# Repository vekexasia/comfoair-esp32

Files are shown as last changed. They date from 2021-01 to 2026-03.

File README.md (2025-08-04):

Need help? Join the [Discord](https://discord.gg/dUSSRezJXC) or open an issue.

# Comfoair Q 350 ESPHome bridge

This software let you use a ESP32 + CAN Transceiver to interact with the Comfoair Q 350 unit.

It does expose all known informations of your Comfoair unit via ESPHOME and let you control the air flow via Home Assistant as well.

It does allow you to integrate the unit on Home Assistant as depicted below:
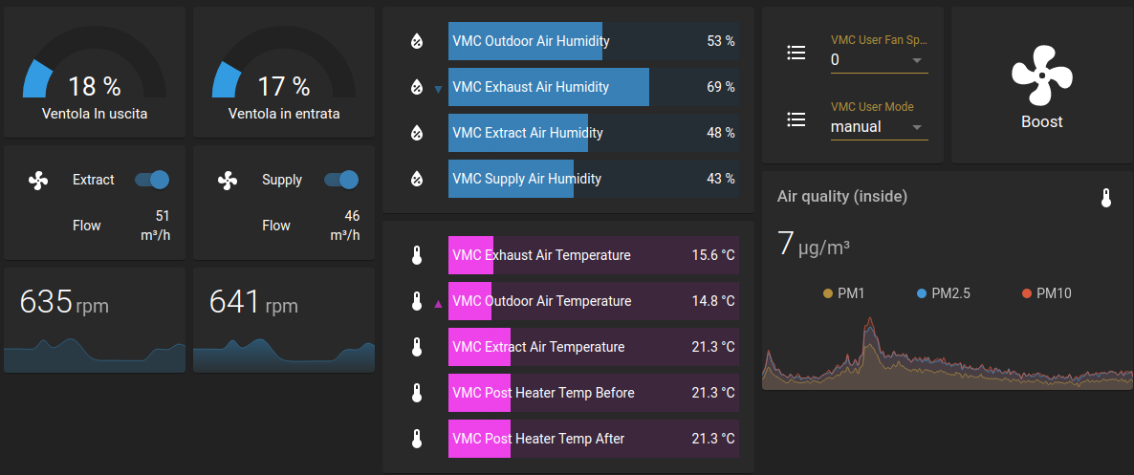
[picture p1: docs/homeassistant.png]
Comfoair Q 350 Home Assistant


## Custom PCB

Inside the [docs/pcb folder](docs/pcb) you can find both gerber file and BOM. Files are provided as is. It's up to you to check data and schematic correctness.

This repository is meant to be working with the custom pcb above. But you can always buy components separately such as [Waveshare SN65HVD230](https://www.banggood.com/Waveshare-SN65HVD230-CAN-Bus-Module-Communication-CAN-Bus-Transceiver-Development-Board-p-1693712.html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) and a voltage regulator as well as an ESP32 of your choice and it will work.

The pcb will look like this once soldered and mounted.

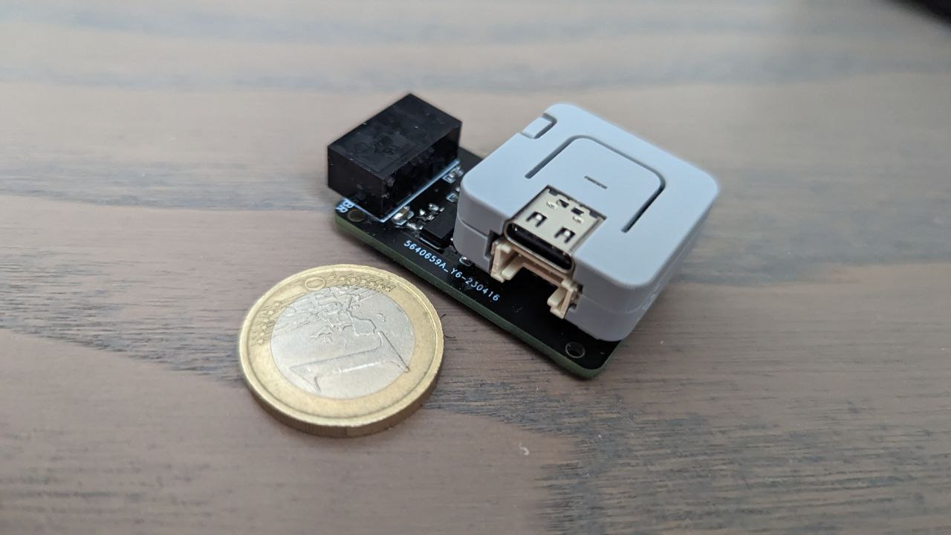
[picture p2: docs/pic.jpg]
PCB Comfoair Q 350 3D Print


## DIY

Prerequisites for custom build:

* `ESP32` -> [link](https://amzn.to/3pe0XVP)
* `DC-DC converter` -> [link](https://amzn.to/39ar22v)
* `RJ45 Female` -> [link](https://amzn.to/3sNx3tH)
* `Can Transceiver` -> [Waveshare SN65HVD230](https://www.banggood.com/Waveshare-SN65HVD230-CAN-Bus-Module-Communication-CAN-Bus-Transceiver-Development-Board-p-1693712.html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)
+ Some ethernet cable

Here a simple schematic. made by @mat3u

```
---------------+        +---------------+                 +-------------+
(oran/red)12V  o--------o IN+      OUT+ o-----------------o VIN         |
               |        |   [LM2596S]   |                 |             |
(brown)   GND  o--------o IN-      OUT- o-----------------o GND         |
               |        +---------------+                 |             |
    [RJ45]     |                                          |   [ESP32]   |
  [ComfoAir]   |                                          |             |
               |        +-------------------------+       |             |
(w/blue) CAN_L o--------o CAN_L               3v3 o-------o 3v3         |
(blue)   CAN_H o--------o CAN_H               GND o-------o GND         |
---------------+        |                         |       |             |
                        |   [SN65HVD230]   CAN TX o-------o 25          |
                        |                  CAN RX o-------o 21          |
                        +-------------------------+       +-------------+
``````

## esphome conf

To include this repo use the external_components configuration like so:

```yaml
# ...
external_components:
  - source: github://vekexasia/comfoair-esp32
    components: [ comfoair ]
api:
  custom_services: true # <--- This is needed

comfoair:

# ...
```

# Home Assistant Services

The component exposes 4 services.

- comfoair_send_command
- comfoair_send_hex
- comfoair_update_all
- comfoair_req_update_service

**NOTE**: the prefix could differ depending on your esphome device name.

**comfoair_send_command**: allows one "command" parameter. The value of the param can be one of the following pre-bundled commands:

- ventilation_level_0
- ventilation_level_1
- ventilation_level_2
- ventilation_level_3
- boost_10_min
- boost_20_min
- boost_30_min
- boost_60_min
- boost_end
- auto
- manual
- bypass_activate_1h
- bypass_deactivate_1h
- bypass_auto
- ventilation_supply_only
- ventilation_supply_only_reset
- ventilation_extract_only
- ventilation_extract_only_reset
- temp_profile_normal
- temp_profile_cool
- temp_profile_warm

In case you need more flexibility you can use the `comfoair_send_hex` service like follows:
```
service: esphome.comfoair_send_hex
data:
  hexSequence: "8415070100000000100e000000"
```
^^ the above is equivalent to ventilation_extract_only (which has an inner timer of 1h)

**comfoair_update_all**: this service will request an update of all the values from the Comfoair unit. This is useful in case you want to force an update of all the values.

**comfoair_req_update_service**: this service will request an update of a specific value from the Comfoair unit. This is useful in case you want to force an update of a specific value. You're required to pass the `PDOID` of the service to update

## Climate Entity

The component will expose a climate entity with heat,cool,auto modes and all the fan speeds.

Furthermore current indoor humidity and temperature as well as current target temperature will be shon as in the picture below.

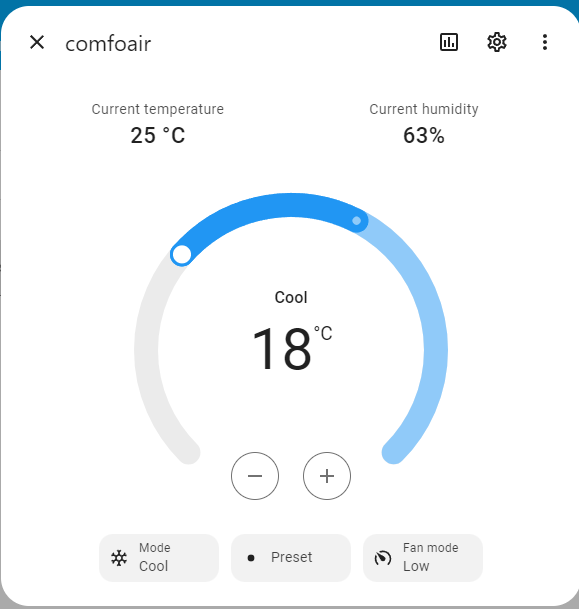
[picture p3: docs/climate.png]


The climate entity can also be used to set the fan speed, and the mode (heat, cool, auto).

## Global filters

Since this component posts data as soon as it receives it, sometimes it might be useful to avoid spamming home assistant with updates.

To avoid this, you can set the `global_filters`. This accepts the same filters as the `filters` parameter in the `sensor` component.

For example, let's say you want to throttle the sensors for 10s.

```yaml

comfoair:
  global_filters:
    - throttle: 10s
```

Obviously, you can always set the filter on a per-sensor basis.

```yaml
comfoair:
  supply_fan_speed:
    name: supply_fan_speed
    disabled_by_default: false
    force_update: false
    unit_of_measurement: rpm
    accuracy_decimals: 0
    filters:
      - or:
          - throttle: 300s
          - delta: 100.0
```

**NOTE**: when setting `global_filters` that **does** takes precedence over the `filters` set on a per-sensor basis.
## Credits

A lot of this repo was inspired by the reverse engineering [here](https://github.com/marco-hoyer/zcan/issues/1).
If you'd like to know more how the unit communicates, head over

* [here](https://github.com/michaelarnauts/aiocomfoconnect/blob/master/docs/PROTOCOL-RMI.md)
* [and here](https://github.com/michaelarnauts/aiocomfoconnect/blob/master/docs/PROTOCOL-PDO.md)

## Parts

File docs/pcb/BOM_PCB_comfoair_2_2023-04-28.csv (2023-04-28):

ID | Name | Designator | Footprint | Quantity | Manufacturer Part | Manufacturer | Supplier | Supplier Part | Price | Pins
1 | 100nF | C1 | C0603 | 1 | CL10B104KO8NNNC | SAMSUNG(三星) | LCSC | C66501 |  | 2
2 | CON4 ATOR PCB MOLEX | CN2 | 39512-1004 | 1 | 39532-1004 | Molex | Mouser | 538-39532-1004 |  | 4
3 | 10kΩ | R1 | R0603 | 1 | 0603WAF1002T5E | UNI-ROYAL(厚声) | LCSC | C25804 |  | 2
4 | 120Ω | R2 | R0603 | 1 | 0603WAF1200T5E | UNI-ROYAL(厚声) | LCSC | C22787 |  | 2
5 | SN65HVD230DR | U1 | SOIC-8_L4.9-W3.9-P1.27-LS6.0-BL | 1 | SN65HVD230DR | TI(德州仪器) | LCSC | C12084 | 0.173 | 8
6 | AMS1117-3.3_C347222 | U3 | SOT-223-4_L6.5-W3.5-P2.30-LS7.0-BR | 1 | AMS1117-3.3 | UMW(广东友台半导体) | LCSC | C347222 | 0.006 | 4
7 | PZ254V-11-04P_C2691448 | H3 | HDR-TH_4P-P2.54-V-M | 1 | PZ254V-11-04P | XFCN(兴飞) | LCSC | C2691448 | 0.004 | 4
8 | PZ254V-11-05P | H4 | HDR-TH_5P-P2.54-V-M | 1 | PZ254V-11-05P | XFCN(兴飞) | LCSC | C492404 | 0.005 | 5
9 | 10uF | C3,C5 | C0603 | 2 | CL10A106MA8NRNC | SAMSUNG(三星) | LCSC | C96446 | 0.004 | 2

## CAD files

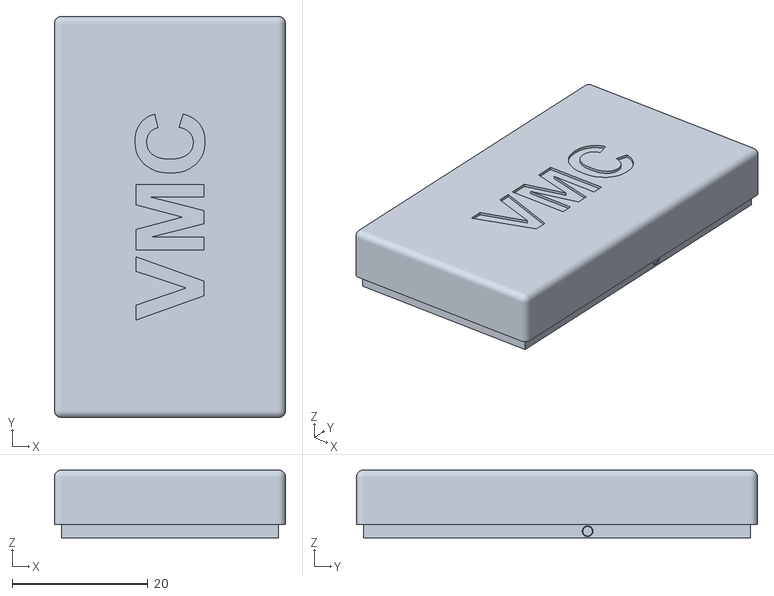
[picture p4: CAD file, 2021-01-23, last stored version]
docs/3d/cappella-box-vmc.stl
34.0 x 59.0 x 10.0

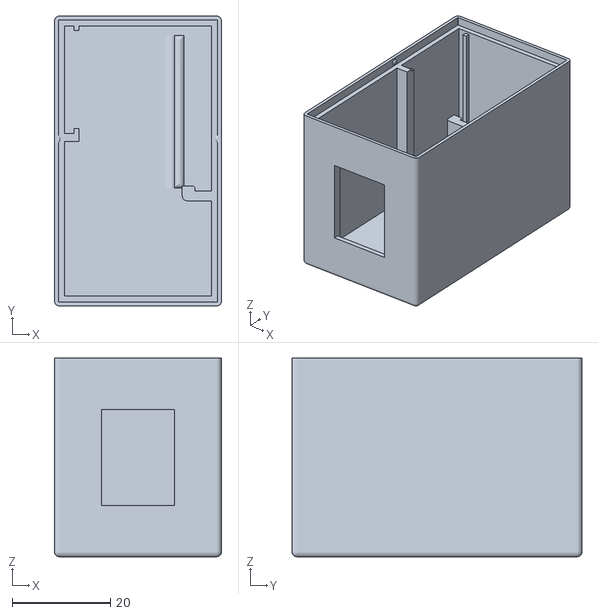
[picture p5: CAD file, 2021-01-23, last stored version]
docs/3d/box-vmc-sotto-finale.stl
34.0 x 59.0 x 40.4

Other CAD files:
docs/3d/box-vmc v20.f3d
docs/box-vmc v20.f3d

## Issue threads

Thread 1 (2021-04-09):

Connection schema for the ESP32 and CAN

asmanea, 2021-04-09:
I hope I'm not asking too much! Could you please upload a connection scheme or image of the end result (not inside the box) between VMC and ESP32/CAN? The steps provided are enough for a skilled person, but for a newbie might be cumbersome to setup. Thanks!

Uriziel01, 2021-06-26:
Just run power (+12V and GND) into the step down converter (set it to output 3.3V first!) and then connect the Step down ouput 3.3V+GND into both ESP32 and the CAN Transceiver. Next connect RX/TX from CAN Transceiver into pins 4 and 5 of ESP32.
Maybe we could create a graphical form of wiring if this will help you ;)

asmanea, 2021-06-26:
Thanks! Will order the parts, and try to do the connection schema. Will update shortly.

Uriziel01, 2021-06-26:
Sure, it is pretty straightforward. I've actually done the build today, should take you around 30minutes.
My only issue was waaaay to small of a box to fit everything inside of it 😄 Now onto HomeAssistant configuration.

vekexasia, 2021-06-26:
Glad to see you did this project. The box is just enough to fit all components but you need to be good at tetris :D

Uriziel01, 2021-06-28:
BTW @vekexasia would you be willing to merge in some MQTT tweaks like implementation of HA MQTT Discovery or migrating commands into using payload instead of just topics. Currently it does not work well with HA without manual synchronization automation scripts.
Not sure if I should just implement this locally or do a PR into your repository? 😉

Uriziel01, 2021-06-28:
@asmanea I've uploaded simple connection diagram so it is easy even for a beginner. Keep in mind (as you can see in the photo) I DID NOT USED this exact diagram because I hate destroying ethernet cables without a reason so I've just plugged in cable into the RJ45 socket and the last 4 pins correspond to the pins on the left (+12V, GND, CAN_H, CAN_L), this way you use just a ethernet cable with RJ45 on both ends.

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

vekexasia, 2021-06-28:
@Uriziel01 ofcourse. Also  if you'd like to add the diagram! that'd be perfect. even if i used the mini format factor.

svde, 2021-06-30:
> RJ45 socket and the last 4 pins correspond to the pins on the left (+12V, GND, CAN_H, CAN_L),

How does this correspond with TIA-568B color coding?

| ComfoAir | RJ45 pin | TIA 568B |
| --- | --- | --- |
| CAN_L | 1 | white-orange |
| CAN_H | 2 | orange |
| GND | 3 | white-green |
| 12V | 4 | blue |

Niki206cc, 2021-07-05:
Good morning, i'm new with HA and ESPN32. I bought all but i want to be sure i will connect correctly because i have a different device. Can you pls confirm me the connections are ok? Thanks
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

svde, 2021-07-05:
> Can you pls confirm me the connections are ok? Thanks

Yes, that's correct.

pistacjusz, 2021-07-06:
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

Are you sure of the attached wiring diagram?
I connected the circuit as shown in the attached below photos, but it doesn't work completely. I can read the values of temperature, humidity, etc. but I cannot change the state of the recuperator (e.g. change the fan speed). I think the HA is sending the mqtt command correctly. Do you have any idea why this doesn't work?
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

svde, 2021-07-06:
> but I cannot change the state of the recuperator (e.g. change the fan speed).
Same here.

I've been trying to investigate (capturing CAN traffic with a raspberry pi + CANhat), haven't figured out what pattern to watch for in the candump output to see if the mqtt command (mosquitto_pub -h 127.0.0.1 -t comfoair/commands/boost_10_min -m 1) is making it onto the canbus.

Uriziel01, 2021-07-18:
@pistacjusz @svde Yes I'm 100% sure because it is working at my place for the last few weeks and except for a WiFi stability issues (not sure what is the problem here, just have to restart the ESP now and then) it is working just fine. Are you sure you are sending correct MQTT msg with corrent topic? Matching your defined `MQTT_PREFIX` from fw files?

pistacjusz, 2021-07-18:
@Uriziel01 On your schematic you connect Can_H recuperator to Can_L transceiver and Can_L recuperator to Can_H transceiver.
When I connect my circuit like this, nothing happens.

Below log from `mosquitto_sub -v -t 'comfoair / commands / #'`

comfoair / commands / ventilation_level 0
comfoair / commands / ventilation_level 1
comfoair / commands / ventilation_level 3
comfoair / commands / set_mode auto
comfoair / commands / set_mode manual
comfoair / commands / ventilation_level 0
comfoair / commands / boost_10_min (null)
comfoair / commands / ventilation_level_3 (null)

and second `mosquitto_sub -v -t 'comfoair / #'`

comfoair / exhaust_fan_speed 805
comfoair / supply_fan_speed 899
comfoair / away_indicator false
comfoair / exhaust_fan_flow 58
comfoair / supply_fan_flow 56
comfoair / ah_actual 0.65
comfoair / exhaust_fan_speed 810
comfoair / supply_fan_speed 901
comfoair / exhaust_fan_flow 59
comfoair / exhaust_fan_speed 813
comfoair / supply_fan_speed 902
comfoair / exhaust_fan_speed 816
comfoair / supply_fan_speed 903
comfoair / exhaust_fan_speed 818

Here line from secrets.h file
#define MQTT_PREFIX "comfoair"

svde, 2021-07-18:
Sending the commands:

$ mosquitto_pub -t comfoair/commands/boost_10_min -m 1
$ mosquitto_pub -t comfoair/commands/boost_10_min -m 2
$ mosquitto_pub -t comfoair/commands/boost_10_min -m 2
$ mosquitto_pub -t comfoair/commands/boost_10_min -m 2

and they show up like this:

$ mosquitto_sub -v -t 'comfoair/commands/#'
comfoair/commands/boost_10_min 1
comfoair/commands/boost_10_min 2
comfoair/commands/boost_10_min 2
comfoair/commands/boost_10_min 2

I'm also running candump, shouldn't I be seeing something like this being sent over the canbus?

#define CMD_boost_10_min                    { 0x84, 0x15, 0x01, 0x06, 0x00, 0x00, 0x00, 0x00, 0x58, 0x02, 0x00, 0x00, 0x03, 0x00, 0x00, 0x00 }

Uriziel01, 2021-07-19:
@pistacjusz Haha, just noticed this :D Of course the correct method is the other way around 😄

Both of your commands seems ok, did you tried to connect to serial of ESP32 and check if it correctly receives the MQTT message and tries to send the CAN command?

pistacjusz, 2021-07-20:
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

There is some data from the serial monitor after sending the MQTT message

```
supply_fan_speed - 1161-------new message from broker-----
channel:comfoair/commands/boost_60_min
data:
Received: boost_60_min
1F034051 00 84 15 01 06 00 00 00
1F034051 01 00 10 0E 00 00 03 00
1F034051 82 00 00
1F054051 00 84 15 01 06 00 00 00
1F054051 01 00 10 0E 00 00 03 00
1F054051 82 00 00
1E4041 X 22 4
Decoded :)
exhaust_fan_speed - 1026354041 X 255 0
Decoded :)

exhaust_fan_speed - 1024354041 X 256 0
Decoded :)
ah_actual - 0.8610000001 X 0
1000001A X 0
10000001 X 0
1000001A X 0
-------new message from broker-----
channel:comfoair/commands/ventilation_level_3
data:
Received: ventilation_level_3
1F074051 00 84 15 01 01 00 00 00
1F074051 81 00 01 00 00 00 03
1F014051 00 84 15 01 01 00 00 00
1F014051 81 00 01 00 00 00 03
1000001A X 0
1E4041 X 28 4
Decoded :)

supply_fan_speed - 1138-------new message from broker-----
channel:comfoair/commands/ventilation_level
data:1
Received: comfoair/commands/ventilation_level
ventilation_level_1
1F034051 00 84 15 01 01 00 00 00
1F034051 81 00 01 00 00 00 01
1F054051 00 84 15 01 01 00 00 00
1F054051 81 00 01 00 00 00 01
688041 X 10
1E4041 X 20 4
Decoded :)
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
Uriziel01, 2022-01-04:
I do not have any option/KNX/LAN box installed, just a can transceiver and it is definitely not getting hot.

piwko28, 2022-01-04:
Thanks for your answer, it's important hint.
I meant voltage between CAN_L and GND and CAN_H and GND. Red connector has 12V as well.
I'll try with another can transceiver then, maybe the one is broken.

piwko28, 2022-01-08:
I had wrong wiring and tried to use espcam. It works perfectly with esp32.

pistacjusz, 2022-02-22:
After many tries, I finally got the project started. The cause of the problems was the factory broken can transciver. I changed it to another one and everything started working immediately, I can read the recuperator states and control it. Greetings:)

quentindavid, 2022-08-26:
Hi, thanks a lot for this project and this topic which are really helpful !
Something I don't quite understand : why would you use the ethernet cable if you can just plug CAN_H, CAN_L, +24V and GND with regular cables in the connector on the left of the RJ45 ?
Is it fine if I connect my CAN transceiver using this port instead of RJ45 ?

Uriziel01, 2022-08-26:
Sure you can use the terminals, the RJ45 is just more convenient, especially when setting things up I had few times some issue and the only way to resolve it was to just physically unplug the RJ45 cable as it was preventing the whole unit from booting up properly.

pyzimmer, 2022-10-18:
I think you can wire the +12v directly to the VIN pin of the ESP32, because ESP board have a regulator. You don't need DC-DC converter.

Uriziel01, 2022-10-18:
@pyzimmer I do not recommend to hook up 12V directly to ESP32 board, it does in fact have a regulator but it is a linear regulator not a switching one, if regulating down from 12V to 5V it will cause regulator to dissipate lots of heat.

At around 160mA-250mA average power draw for ESP32 and 7V potential difference (12-5) it's around 1.12W to 1.75W of power that will get converter into heat. It's fine for a short period but in this case device will run 24/7.

Hans-0, 2023-01-10:
For this project I am using the D1 Mini ESP32 ESP-32 Wifi + Bluetooth (CP2102) - see image:

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

Vekexasia says in his description:
can_rx -> pin 5 of esp32
can_tx -> pin 4 of esp32

Which pins are those exactly on my esp32?

Uriziel01, 2023-01-10:
**D4** is the **GPIO4** (**IO4** in your case)
**D5** is the **GPIO5** (**IO5** in your case)

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

rpiLovers, 2023-06-21:
Hi, thanks a lot for this project and this topic!
I just need some help with installation (ESPHOME newbie....)
I have WT32-ETH01 ESP32  board, Waveshare SN65HVD230 CAN Tranceiver Module and Buck Converter LM2596 3A.
In home assistant I see the ESP board and all of the parameters (i used the external_components:   - source: github://vekexasia/comfoair-esp32).
The problem is that I am not sure which ports to use and to change in the code.
I think RXD (GPIO05) and TXD (GPIO17).
How can I change the code in ESPHOME? Your board uses PIn 4 and 5.
Hope someone can helpout.
I would love to get my Q450 working on the network.
Thanks in advance.
HDR

pat1300, 2023-06-21:
> @asmanea I've uploaded simple connection diagram so it is easy even for a beginner. Keep in mind (as you can see in the photo) I DID NOT USED this exact diagram because I hate destroying ethernet cables without a reason so I've just plugged in cable into the RJ45 socket and the last 4 pins correspond to the pins on the left (+12V, GND, CAN_H, CAN_L), this way you use just a ethernet cable with RJ45 on both ends.
>
> 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

@Uriziel01 : Hi, are you sure of your connection diagram? CAN_L (white wire) is connected to CANH of the transceiver , and CAN_H ( yellow) is conncetd to CANL . I think it should be the reverse.  Your photos are correct, but not the diagram I think.
Best regards,
Patrick

Uriziel01, 2023-06-22:
@pat1300 Just checked and I'm sure of the fact that it is definetly wrong 😄 **Of course CAN_L should be connected to CANL and CAN_H to CANH.**

@rpiLovers I guess you can just change 25/21 pins combo in the `comfoair-esp32/components/comfoair
/__init__.py` file. @vekexasia mentioned that he will be possibly adding custom pins configuration in the near future here https://github.com/vekexasia/comfoair-esp32/issues/46#issuecomment-1533125530

poingZ, 2023-06-27:
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

@pat1300 are you powering the ESP32 with the 3.3V DC-DC convertor? My setup doesn't work and can't find out why, I'm powering the ESP32 (mini) via USB and the ESP32 is giving 3.3v to the CAN module (I measured it). I don't see why this shouldn't work ...

vekexasia, 2024-03-11:
Hello @Uriziel01 @pat1300 @rpiLovers You can now do it via rx_pin and tx_pin configuration flags

Closed 2024-03-11.

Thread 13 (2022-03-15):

Help to install on ESP32

bekaxe, 2022-03-15:
Can anyone provide a short description on how to install this on an ESP32?
Or refer to a proper documentation?

I managed to install the included libraries wifi, comfoair, mqtt and ota by adding them to the libraries folder of the IDE.
But it is missing the esp32_can.h
Where do I find the correct library for the CAN controller?

tobiaranz, 2022-03-16:
Hi, I managed to install on ESP32 using VS code with platformio extension. I only had to add secrets.h in src folder (defining WIFI_SSID, WIFI_PASS, MQTT_USER, MQTT_PASS, MQTT_PREFIX "comfoair", MQTT_HOST and MQTT_PORT).
After that I had to add the lib "knolleary/PubSubClient@^2.8" under lib_deps in platformio.ini file.

I'm not sure if this is the best way to set everything up, but it worked for me, hope this helps you.

bekaxe, 2022-03-18:
@tobiaranz: thanks for the hint, I have done this and it helped me to get further.
I have now a dependency which I do not get resolved.
`.pio/libdeps/esp12e/FreeRTOS-Kernel/include/FreeRTOS.h:59:10: fatal error: FreeRTOSConfig.h: No such file or directory`

Which is the right lib to include?

makselod, 2022-04-16:
Hi all,
its my first time with visual studio.

Can some one tell me what I must do to upload?

`Verbose mode can be enabled via `-v, --verbose` option
CONFIGURATION: https://docs.platformio.org/page/boards/espressif32/mhetesp32minikit.html
PLATFORM: Espressif 32 (3.5.0) > MH ET LIVE ESP32MiniKit
HARDWARE: ESP32 240MHz, 320KB RAM, 4MB Flash
DEBUG: Current (esp-prog) External (esp-prog, iot-bus-jtag, jlink, minimodule, olimex-arm-usb-ocd, olimex-arm-usb-ocd-h, olimex-arm-usb-tiny-h, olimex-jtag-tiny, tumpa)
PACKAGES:
 - framework-arduinoespressif32 3.10006.210326 (1.0.6)
 - tool-esptoolpy 1.30100.210531 (3.1.0)
 - tool-mkspiffs 2.230.0 (2.30)
 - toolchain-xtensa32 2.50200.97 (5.2.0)
LDF: Library Dependency Finder -> https://bit.ly/configure-pio-ldf
LDF Modes: Finder ~ chain, Compatibility ~ soft
Found 31 compatible libraries
Scanning dependencies...
Dependency Graph
|-- <SPI> 1.0
|-- <can_common> 0.3.0+sha.07605a2
|-- <ESP32_CAN> 0.2.5+sha.7c3174f
|   |-- <can_common> 0.3.0+sha.07605a2
|   |-- <SPI> 1.0
|-- <PubSubClient> 2.8.0
|-- <WiFi> 1.0
|-- <ESPmDNS> 1.0
|   |-- <WiFi> 1.0
|-- <Update> 1.0
|-- <WebServer> 1.0
|   |-- <WiFi> 1.0
|   |-- <FS> 1.0
Building in release mode
Compiling .pio\build\esp32minikit\src\comfoair\CanAddress.cpp.o
In file included from src\comfoair\CanAddress.cpp:2:0:
src\comfoair\CanAddress.h:5:15: fatal error: map: No such file or directory
compilation terminated.
Compiling .pio\build\esp32minikit\src\comfoair\PubSubClient.cpp.o
Compiling .pio\build\esp32minikit\src\comfoair\comfoair.cpp.o
Compiling .pio\build\esp32minikit\src\comfoair\message.cpp.o
*** [.pio\build\esp32minikit\src\comfoair\CanAddress.cpp.o] Error 1
In file included from src\comfoair\PubSubClient.h:10:0,
                 from src\comfoair\PubSubClient.cpp:8:
C:\Users\daro1\.platformio\packages\framework-arduinoespressif32\cores\esp32/Arduino.h:142:21: fatal error: algorithm: No such file or directory
compilation terminated.
In file included from .pio\libdeps\esp32minikit\PubSubClient\src/PubSubClient.h:10:0,
                 from src\comfoair\message.h:5,
                 from src\comfoair\message.cpp:1:
C:\Users\daro1\.platformio\packages\framework-arduinoespressif32\cores\esp32/Arduino.h:142:21: fatal error: algorithm: No such file or directory
compilation terminated.
In file included from .pio\libdeps\esp32minikit\PubSubClient\src/PubSubClient.h:10:0,
                 from src\comfoair\message.h:5,
                 from src\comfoair\comfoair.h:3,
                 from src\comfoair\comfoair.cpp:1:
C:\Users\daro1\.platformio\packages\framework-arduinoespressif32\cores\esp32/Arduino.h:142:21: fatal error: algorithm: No such file or directory
compilation terminated.
*** [.pio\build\esp32minikit\src\comfoair\PubSubClient.cpp.o] Error 1
*** [.pio\build\esp32minikit\src\comfoair\comfoair.cpp.o] Error 1
*** [.pio\build\esp32minikit\src\comfoair\message.cpp.o] Error 1
============================================================ [FAILED] Took 7.20 seconds ============================================================
Environment    Status    Duration
-------------  --------  ------------
esp32minikit   FAILED    00:00:07.199`

pyto00, 2022-05-10:
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

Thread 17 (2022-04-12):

Esp getting into hanging state after 1-3 days neither sending or receiving data.

Erestes, 2022-04-12:
First of all thanks for the great work on this, works flawlessly with a small but.
My ESP hangs every 1,2,3 days and I need o shut down the unit and enable it back again to restore readings and control. I got the power supplied from the recu, my friend has a separate power via phone charger and it works for him without any issues. Any ideas what may be causing the issues in my case?

vekexasia, 2022-04-12:
Hey, you're not the first one to tell me such issue. Unfortunately my esp32 is running stable since months now. Not a single time I had to powercycle it.

What board are you using? How distant is the WiFi AP from the ESP32?

Erestes, 2022-04-12:
I'm using ESP-WROOM-32
Distance between AP - ESP ca 7-8m through two walls, signal readings on the router = Medium but okay
I have another ESP for voltage/current readings which is bit furhter away and works without issues. I would remove the wifi signal from the equation.
What I haven't done and what I will check next time when it happens is whether the ESP is responding to pings while in hang state.
I wonder if a periodic restart on ESP (for example at midnight) would help, but still wouldn't know what piece of code should be added and where.

Erestes, 2022-04-15:
Interestingly since I posted this issue the ESP didn't crash so far :)

Closed 2022-09-12.

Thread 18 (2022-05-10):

Option Box Connection Error

atomic339, 2022-05-10:
Hi, everything is working good. But I get error "option box connection error". I have to reconnect everything and error disappears but after few hours I get it again.
All commands from mqtt work good, even error appears.

vekexasia, 2022-09-12:
I think the id of the device might conflict to the option box? Did you get this sorted?

atomic339, 2022-09-12:
In my case it was a 2 problems:
- DC-DC converter (I changed to micro usb power supply and works good)
- after wifi lost esp32 can't connect again (someone post here "wifi loop command" - I compiled with this loop and works good)

After this works stable and great

Closed 2022-09-12.

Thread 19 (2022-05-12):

assert failed: xTaskRemoveFromEventList tasks.c

pyto00, 2022-05-12:
I am struggeling with this assert fail error. I found that this is a part of FreeRTOS which I have no knowledge about.
It reboots a few times and then gets stuck.

From the monitor terminal

```
Connecting to INET
.......
WiFi Connected. IP:
192.168.0.45
ESP_SMT init
ESPVMC init
Attempting MQTT connection...connected
Subscribing to: comfoair/commands/auto
Subscribing to: comfoair/commands/boost_10_min

assert failed: xTaskRemoveFromEventList tasks.c:3657 (pxUnblockedTCB)

Backtrace:0x40083835:0x3ffb23400x4008b7e9:0x3ffb2360 0x40090ca9:0x3ffb2380 0x4008d586:0x3ffb24b0 0x4008c8b8:0x3ffb24d0 0x40100c32:0x3ffb2510 0x40100f61:0x3ffb2530 0x400efb26:0x3ffb2550 0x400f14b8:0x3ffb2580 0x400ead15:0x3ffb2620 0x400d8522:0x3ffb2690 0x400d7ab0:0x3ffb26f0 0x400d7e1d:0x3ffb2710 0x400d7e35:0x3ffb2730 0x400d4adb:0x3ffb2750 0x400d4ba3:0x3ffb2790 0x400d4c1e:0x3ffb27e0 0x400d49bc:0x3ffb2800 0x400e0b51:0x3ffb2820
```

Does someone has any pointers for me ?

svde, 2022-05-12:
Same as in my (updated) [comment](https://github.com/vekexasia/comfoair-esp32/issues/13#issuecomment-1123989770) on a previous issue.

pyto00, 2022-05-13:
The code written by @vekexasia is not compatible anymore with the latest ESPRESSIF32 platform.
I went to this overview of all the versions to see what version they where at now.

[https://registry.platformio.org/platforms/platformio/espressif32/versions?version=3.3.0](url)

I then randomly chose a version from 10 months ago.
and edited the platformio.ini config like below.

```
[env:nodemcu-32s]`
platform = platformio/espressif32@3.3.0
board = esp32dev
framework = arduino
monitor_speed = 115200
upload_port = COM20
monitor_port = COM20
lib_deps =
    SPI
	can_common=https://github.com/collin80/can_common.git
	esp32_can=https://github.com/collin80/esp32_can.git
	https://github.com/knolleary/pubsubclient.git
```

the ESP32 does not crash anymore and I was able to send a command.
```
Connecting to INET
.........
WiFi Connected. IP:
192.168.0.45
ESP_SMT init
ESPVMC init
Attempting MQTT connection...connected
Subscribing to: comfoair/commands/auto
Subscribing to: comfoair/commands/boost_10_min
Subscribing to: comfoair/commands/boost_20_min
Subscribing to: comfoair/commands/boost_30_min
Subscribing to: comfoair/commands/boost_60_min
Subscribing to: comfoair/commands/boost_end
Subscribing to: comfoair/commands/bypass_activate_1h
Subscribing to: comfoair/commands/bypass_auto
Subscribing to: comfoair/commands/bypass_deactivate_1h
Subscribing to: comfoair/commands/manual
Subscribing to: comfoair/commands/set_mode
Subscribing to: comfoair/commands/temp_profile_cool
Subscribing to: comfoair/commands/temp_profile_normal
Subscribing to: comfoair/commands/temp_profile_warm
Subscribing to: comfoair/commands/ventilation_extract_only
Subscribing to: comfoair/commands/ventilation_extract_only_reset
Subscribing to: comfoair/commands/ventilation_level
Subscribing to: comfoair/commands/ventilation_level_0
Subscribing to: comfoair/commands/ventilation_level_1
Subscribing to: comfoair/commands/ventilation_level_2
Subscribing to: comfoair/commands/ventilation_level_3
Subscribing to: comfoair/commands/ventilation_supply_only
Subscribing to: comfoair/commands/ventilation_supply_only_reset
-------new message from broker-----
channel:comfoair/commands/ventilation_level_3
data:
Received: ventilation_level_3
1F034051 00 84 15 01 01 00 00 00
1F034051 81 00 01 00 00 00 03
1F054051 00 84 15 01 01 00 00 00
1F054051 81 00 01 00 00 00 03
```

vekexasia, 2022-05-13:
hey @pyto00 can you please open a merge request?

piotrsn, 2022-06-17:
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

This helped me a lot - thank you. The script is now fully working.

vekexasia, 2022-06-17:
Heyhey @piotrsn can you create a MR?

piotrsn, 2022-06-17:
Hey, to be honest I am soo new to this that I don't know how to do it. If
you can give me a guide or a link how to do so, then I will do. Thank you

pt., 17 cze 2022 o 10:55 Andrea ***@***.***> napisał(a):

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

atomic339, 2022-06-27:
If I want to use nodemcu 32S bord do I need to add:
[env:nodemcu-32s] in platformio.ini?

pyto00, 2022-07-03:
> hey @pyto00 can you please open a merge request?

Hi,

The merge request is still pending. Can you initiate the merge ?

vekexasia, 2022-07-03:
sorry pyto didn't see the MR for some reason. I just merged.

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

--

Andrea Baccega
[image: ***@***.***
[image: ***@***.***
[image: Personal site] <http://www.andreabaccega.com/> [image: Linkedin
Profile] <http://it.linkedin.com/in/andreabaccega> [image: Facebook]
<https://www.facebook.com/andrea.baccega> [image: Google+]
<https://plus.google.com/109217393200753135791> [image: Twitter]
<http://twitter.com/veke87> [image: StackOverflow]
<http://stackoverflow.com/users/314407/andrea-baccega> [image: GitHub]
<https://github.com/vekexasia>

Closed 2022-09-12.

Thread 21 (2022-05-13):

commands not accepted by comfoair unit

pyto00, 2022-05-13:
When the ESP32 is connected to the canbus I get an error on de display of the unit itself
`Comfonet error Please check cables`

I can only reset this error when I disconnect the ESP32.
While connected I am able to read out the sensor data but the unit doesn't react on commands.

Comfoair Firmware 1.9.0

Can this be a canbus ID error ? Maybe due to the recent firmare on the comfoair unit ?
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

panosnl, 2022-07-22:
I can send commands without errors to the Q600 with firmware 1.9.1

I only get this error when the eps restarts.

masafra86, 2022-10-01:
I have the same problem, I can't send commands. I receive all the correct data (even if 15/20 minutes after resetting the ESP, connection fails), but I am not able to send commands. Firmware version R1.9.0

masafra86, 2022-11-01:
Today I got again to work on my ESP32 to try to understand the problem, and monitoring the ESP while I was trying to send any command, I found that it never receives any command message. I got back to build the firmware and I found in the logs this:

mpiling .pio/build/az-delivery-devkit-v4/src/main.cpp.o
Compiling .pio/build/az-delivery-devkit-v4/src/mqtt/mqtt.cpp.o
src/comfoair/comfoair.cpp: In member function 'void comfoair::ComfoAir::setup()':
src/comfoair/comfoair.cpp:24:4: warning: ISO C++ forbids converting a string constant to 'char*' [-Wwrite-strings]
   });
    ^
src/comfoair/comfoair.cpp:42:5: note: in expansion of macro 'subscribe'
     subscribe("ventilation_level_0");
     ^
src/comfoair/comfoair.cpp:24:4: warning: ISO C++ forbids converting a string constant to 'char*' [-Wwrite-strings]
   });
    ^
src/comfoair/comfoair.cpp:43:5: note: in expansion of macro 'subscribe'
     subscribe("ventilation_level_1");
     ^
src/comfoair/comfoair.cpp:24:4: warning: ISO C++ forbids converting a string constant to 'char*' [-Wwrite-strings]
   });
    ^
src/comfoair/comfoair.cpp:44:5: note: in expansion of macro 'subscribe'
     subscribe("ventilation_level_2");
     ^
src/comfoair/comfoair.cpp:24:4: warning: ISO C++ forbids converting a string constant to 'char*' [-Wwrite-strings]
   });
    ^
src/comfoair/comfoair.cpp:45:5: note: in expansion of macro 'subscribe'
     subscribe("ventilation_level_3");
     ^
src/comfoair/comfoair.cpp:24:4: warning: ISO C++ forbids converting a string constant to 'char*' [-Wwrite-strings]
   });
    ^
src/comfoair/comfoair.cpp:46:5: note: in expansion of macro 'subscribe'
     subscribe("boost_10_min");
     ^
src/comfoair/comfoair.cpp:24:4: warning: ISO C++ forbids converting a string constant to 'char*' [-Wwrite-strings]
   });
    ^
src/comfoair/comfoair.cpp:47:5: note: in expansion of macro 'subscribe'
     subscribe("boost_20_min");
     ^
src/comfoair/comfoair.cpp:24:4: warning: ISO C++ forbids converting a string constant to 'char*' [-Wwrite-strings]
   });
    ^
src/comfoair/comfoair.cpp:48:5: note: in expansion of macro 'subscribe'
     subscribe("boost_30_min");
     ^
src/comfoair/comfoair.cpp:24:4: warning: ISO C++ forbids converting a string constant to 'char*' [-Wwrite-strings]
   });
    ^
src/comfoair/comfoair.cpp:49:5: note: in expansion of macro 'subscribe'
     subscribe("boost_60_min");
     ^
src/comfoair/comfoair.cpp:24:4: warning: ISO C++ forbids converting a string constant to 'char*' [-Wwrite-strings]
   });
    ^
src/comfoair/comfoair.cpp:50:5: note: in expansion of macro 'subscribe'
     subscribe("boost_end");
     ^
src/comfoair/comfoair.cpp:24:4: warning: ISO C++ forbids converting a string constant to 'char*' [-Wwrite-strings]
   });
    ^
src/comfoair/comfoair.cpp:51:5: note: in expansion of macro 'subscribe'
     subscribe("auto");
     ^
src/comfoair/comfoair.cpp:24:4: warning: ISO C++ forbids converting a string constant to 'char*' [-Wwrite-strings]
   });
    ^
src/comfoair/comfoair.cpp:52:5: note: in expansion of macro 'subscribe'
     subscribe("manual");
     ^
src/comfoair/comfoair.cpp:24:4: warning: ISO C++ forbids converting a string constant to 'char*' [-Wwrite-strings]
   });
    ^
src/comfoair/comfoair.cpp:53:5: note: in expansion of macro 'subscribe'
     subscribe("bypass_activate_1h");
     ^
src/comfoair/comfoair.cpp:24:4: warning: ISO C++ forbids converting a string constant to 'char*' [-Wwrite-strings]
   });
    ^
src/comfoair/comfoair.cpp:54:5: note: in expansion of macro 'subscribe'
     subscribe("bypass_deactivate_1h");
     ^
src/comfoair/comfoair.cpp:24:4: warning: ISO C++ forbids converting a string constant to 'char*' [-Wwrite-strings]
   });
    ^
src/comfoair/comfoair.cpp:55:5: note: in expansion of macro 'subscribe'
     subscribe("bypass_auto");
     ^
src/comfoair/comfoair.cpp:24:4: warning: ISO C++ forbids converting a string constant to 'char*' [-Wwrite-strings]
   });
    ^
src/comfoair/comfoair.cpp:56:5: note: in expansion of macro 'subscribe'
     subscribe("ventilation_supply_only");
     ^
src/comfoair/comfoair.cpp:24:4: warning: ISO C++ forbids converting a string constant to 'char*' [-Wwrite-strings]
   });
    ^
src/comfoair/comfoair.cpp:57:5: note: in expansion of macro 'subscribe'
     subscribe("ventilation_supply_only_reset");
     ^
src/comfoair/comfoair.cpp:24:4: warning: ISO C++ forbids converting a string constant to 'char*' [-Wwrite-strings]
   });
    ^
src/comfoair/comfoair.cpp:58:5: note: in expansion of macro 'subscribe'
     subscribe("ventilation_extract_only");
     ^
src/comfoair/comfoair.cpp:24:4: warning: ISO C++ forbids converting a string constant to 'char*' [-Wwrite-strings]
   });
    ^
src/comfoair/comfoair.cpp:59:5: note: in expansion of macro 'subscribe'
     subscribe("ventilation_extract_only_reset");
     ^
src/comfoair/comfoair.cpp:24:4: warning: ISO C++ forbids converting a string constant to 'char*' [-Wwrite-strings]
   });
    ^
src/comfoair/comfoair.cpp:60:5: note: in expansion of macro 'subscribe'
     subscribe("temp_profile_normal");
     ^
src/comfoair/comfoair.cpp:24:4: warning: ISO C++ forbids converting a string constant to 'char*' [-Wwrite-strings]
   });
    ^
src/comfoair/comfoair.cpp:61:5: note: in expansion of macro 'subscribe'
     subscribe("temp_profile_cool");
     ^
src/comfoair/comfoair.cpp:24:4: warning: ISO C++ forbids converting a string constant to 'char*' [-Wwrite-strings]
   });
    ^
src/comfoair/comfoair.cpp:62:5: note: in expansion of macro 'subscribe'
     subscribe("temp_profile_warm");
     ^
src/comfoair/comfoair.cpp:70:6: warning: ISO C++ forbids converting a string constant to 'char*' [-Wwrite-strings]
     });
      ^
src/comfoair/comfoair.cpp:80:6: warning: ISO C++ forbids converting a string constant to 'char*' [-Wwrite-strings]
     });
      ^

I'm not able to understand what is he saying, but maybe someone has the solution

Closed 2024-03-11.

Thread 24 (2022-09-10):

New configuration for mqtt 2022.12.0

atomic339, 2022-09-10:
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

Do you make a new configuration or the old one will work?

vekexasia, 2022-09-10:
I did change mine. I might commit a new version

atomic339, 2022-09-11:
If you can it will be great

atomic339, 2022-09-15:
Can you help me with this changes?
Put this to my config but sensors don't work:
mqtt:
  sensor:
    # Consumption
    - name: "VMC Power Current"
      state_topic: "comfoair/power_consumption_current"
      unit_of_measurement: W
    - name: "VMC Total Energy Saving"
      state_topic: "comfoair/ah_ytd"
      unit_of_measurement: Wh

# FAns
    - name: "VMC Exhaust Fan Speed"
      state_topic: "comfoair/exhaust_fan_speed"
      unit_of_measurement: rpm
    - name: "VMC Supply Fan Speed"
      state_topic: "comfoair/supply_fan_speed"
      unit_of_measurement: rpm
    - name: "VMC Exhaust Fan Duty"
      state_topic: "comfoair/exhaust_fan_duty"
      unit_of_measurement: rpm
    - name: "VMC Supply Fan Duty"
      state_topic: "comfoair/supply_fan_duty"
      unit_of_measurement: rpm
    - name: "VMC Supply Fan User Speed"
      state_topic: "comfoair/fan_speed"

  # FLOW
    - name: "VMC Exhaust   Fan Flow"
      state_topic: "comfoair/exhaust_fan_flow"
      unit_of_measurement: "m³/h"
    - name: "VMC Supply Fan Flow"
      state_topic: "comfoair/supply_fan_flow"
      unit_of_measurement: "m³/h"

# TEMPS
    - name: "VMC Outdoor Air Temperature"
      state_topic: "comfoair/outdoor_air_temp"
      unit_of_measurement: "°C"
    - name: "VMC Exhaust Air Temperature"
      state_topic: "comfoair/exhaust_air_temp"
      unit_of_measurement: "°C"
    - name: "VMC Extract Air Temperature"
      state_topic: "comfoair/extract_air_temp"
      unit_of_measurement: "°C"
    - name: "VMC Post Heater Temp Before"
      state_topic: "comfoair/post_heater_temp_before"
      unit_of_measurement: "°C"
    - name: "VMC Post Heater Temp After"
      state_topic: "comfoair/post_heater_temp_after"
      unit_of_measurement: "°C"

# Humidity
    - name: "VMC Outdoor Air Humidity"
      state_topic: "comfoair/outdoor_air_humidity"
      unit_of_measurement: "%"
    - name: "VMC Exhaust Air Humidity"
      state_topic: "comfoair/exhaust_air_humidity"
      unit_of_measurement: "%"
    - name: "VMC Extract Air Humidity"
      state_topic: "comfoair/extract_air_humidity"
      unit_of_measurement: "%"
    - name: "VMC Supply Air Humidity"
      state_topic: "comfoair/supply_air_humidity"
      unit_of_measurement: "%"

atomic339, 2022-09-15:
Ok, it was a problem with my board. Works good

Closed 2022-09-15.

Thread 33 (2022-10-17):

Integration with existing UI for CA350

mat3u, 2022-10-17:
Hello,

I was tinkering over weekend to make working this firmware with existing Lovelace controls (eg. https://github.com/mweimerskirch/lovelace-hacomfoairmqtt). Result:

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
I can see temperatures, fan duty and can control fan level.

I made some changes, some of them makes sens (like last will) other probably could be handled by HA itself by smart configuration. Eg.:
```
fan_mode_command_topic: "comfoair/climate/fan/set"
fan_mode_state_topic: "comfoair/climate/fan"
fan_modes:
  - off
  - low
  - medium
  - high
 ```
Instead changing firmware these topics could be done using templates, but I was unable to write template that is working and produces results I want.

You can see changes I made and pieces of configuration here: https://github.com/mat3u/comfoair-esp32/tree/hacomfoairmqtt-compatibility. If any of this features is interesting then, let me know.

vekexasia, 2022-10-17:
Hello @mat3u thanks for bringing to my attention that project. I was not aware of that. I've quickly gone over your changes and there are a lot that are basically reformatting the code.

If you could manage to remove the reformatting changes and keep compatibility to the current mqtt topics that would be a nice addition. Also for your 3d case which should allow more space than mine which does not leave much room.

mat3u, 2022-10-17:
Yeah, my editor reformated whatever I've touched, but current code is a little bit inconsistent ;) Maybe you have a preferred `.editorconfig` that I can use with VSCode to reformat it properly?

I can add old MQTT Topics without any problem and cleanup README.md a little bit. I'll work on that.

mat3u, 2022-10-17:
I reverted most of the auto-reformat things. I'll make some changes to make it backward-compatible.

I suggest, to reformat whole repository in single PR, as it will be hard to develop in this repository without it.

jakubko186, 2022-11-22:
Can you see animation of the level 0 (fan off) button? After clicking level 0 it works (sends correct mqtt command), but I still see in blue only the level I've used before :(
Levels 1, 2 and 3 works fine.

mat3u, 2022-11-26:
Yeah, it is also not working in my setup. I was digging yesterday into it, and it seems like HA is not respecting list of values to be parsed, and only passes default values. I'll try to debug it further.

mat3u, 2022-11-27:
Hey, I've been digging into it, and it seems that `off` is some keyword that has more meaning. My climate configuration looks like this rn:
```
  fan_mode_command_topic: "comfoair/climate/fan/set"
  fan_mode_state_topic: "comfoair/climate/fan"
  fan_modes:
    - "off"
    - low
    - medium
    - high
  ```

You may notice that `off` is wrapped by `"`.
Also, Climate seem to be much more cooperative when I commented out whole `mode` section. It was generating a lot of errors and warnings.

Closed 2024-07-04.

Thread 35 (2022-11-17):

No MQTT

Obelixje, 2022-11-17:
Hi,

There is no MQTT traffic coming from the esp32.
Is there a way to check logging on the ESP32?

When connecting to the IP of the ESP32 directly I only see possibility to upload files.

mikka2, 2022-11-17:
You can check if ESP32 is sending data by connecting to MQTT broker that you set and check for incoming messages.

Obelixje, 2022-11-18:
There are no incoming messages on the broker.

Do we ONLY expect messages when there is data coming in from Comfoair?
I am asking this because I may have blew up the Can tranceiver.

Or do we expect messages always when ESP is on the wifi. (Even when comfoair is not yet connected)?

gsabbe, 2022-11-18:
In my experience messages are sent as they are received and decoded from
the comfoair.
Also the comfoair seems to only send data as it changes. So it took two
hours for all my variables to be set in Home Assistant.
One amelioration would be to send a status message every 60 seconds or so
just to say "I'm online".

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

Obelixje, 2022-11-18:
ok,
thanks.
My first impression was that the Can tranciever is defect. It could be the case that I have to wait some hours for the first message..
Thanks for your help'

gsabbe, 2022-11-18:
Things like fan speed would change rather quickly and are the first
messages I saw coming in. Can you connect your laptop to the ESP and open
the arduino console?
This way you'd see the message coming in, and perhaps triple check your
MQTT settings. (I managed to mess up the port and password when setting it
up the first time :))
I also blew up my ESP32 because I didn't tune the DC-DC step down to 3.3V
from the 12V set at the factory. The CAN module didn't care about the over
voltage thankfully.
Late night projects are always fun.

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

Obelixje, 2022-11-18:
LOL

Same thing happened to me, also blew up the ESP32 because of the 12v...
I did triple test the incoming voltage (+/-), but did not check the outcoming voltage. So on my first connection I blew up the esp32, and an errormessage of the Comfoair.

I am going to connect the esp32 to Arduino, and see if something happens.

gsabbe, 2022-11-18:
My comfoairq actually shutdown completely with my mistake, rather scary.
But it came back to life after unplugging/replugging the power.
The ESP 5V pin is a lot more tolerant and accepts unregulated 5-12V. But
the 3.3V wants regulated 3.3V and nothing else.

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

Obelixje, 2022-11-18:
Is is working, the schedule was not correct.
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

CanH and CANL were switched....

Obelixje, 2022-11-18:
@gsabbe
Thanks for your help this morning?
Do you have a good dashboard (yaml) that you can share?

Obelixje, 2022-11-19:
All solved. Wiring issue....

Closed 2022-11-19.

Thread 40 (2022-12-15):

How to connect

Obelixje, 2022-12-15:
Hi,

How can guide me to the best startup solution?
I am currently connecting to the Q450 using the RJ45 port.

- If I connect the project to the powered off Q450 and then power on the Q450, the Q450 does not start
- If I connect the project to a completely started Q450 there is an errormessage telling me there is something wrong with the cabling.
- If I connect directly after powering on sometimes it all works.

What is the best methode?
Is there a difference between using the RJ450 port or the white connectore?

bakermat, 2022-12-15:
Have a look at #1, the cabling schema on the main page for RJ45 seems to be incorrect. I ran into the same issue, I used [this one](https://github.com/vekexasia/comfoair-esp32/issues/1#issuecomment-871412942) and can confirm that works for the RJ45 connection.

Obelixje, 2022-12-16:
@bakermat

I don't think cabling is the issue here.
The project did work. Only this week the supplier came by for maintenance on my heater. This guy also delivered the Q450.
I didn't want him to know that I hooked something up because of warranty. So I removed it.
After this I am unable to connect anymore.

I have still all setup un a breadboard, maybe one ore more of the connections are not good anymore.
I am going to check this today/tomorrow.

Thanks for your response.

But regarding powering up.
do you power up the Q, and then connect the ESP, or have it already connected and then power up?

bakermat, 2022-12-16:
You can connect the RJ45 when the Qx50 is powered up, no need to power down the unit first. If you're fiddling with the white ports and cabling them one by one from a breadboard then make sure to turn off the unit to be safe.

Obelixje, 2022-12-16:
Thanks,

I have just replaced the CAN.
Now I can power up the Q when the board is already connected. So probably CAN was broken.
Only not yet MQTT messages...

Obelixje, 2022-12-16:
Maybe also the ESP32 is broken? Or at least the ports..
There are no MQTT messages send.

Obelixje, 2022-12-17:
The red light on the esp does blink when it esp is on 3.3 v. no wifi, no mqtt
When I connect to 5 v there is no blinking, hooked on wifi , no mqtt

Probably esp is broken. Tonight a new one is delivered from Amazon. I will probably test tomorrow.

Obelixje, 2022-12-18:
Also with new esp32 no mqtt coming from the esp32.
The esp32 is online.

Is there a way to see the logging from the esp?

Obelixje, 2022-12-18:
When I try to reprogram the esp32 i see that the 2nd part is failing. (wifi)
Is this important? Because through wire already passes.

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

Obelixje, 2022-12-19:
Maybe my 2nd Can Transceiver is also broken?
If not it might be I blew up something in my Q450...

Obelixje, 2022-12-29:
New Can transceiver did solve the issue.
Up and running again!

Obelixje, 2022-12-29:
New Can transceiver did solve the issue.
Up and running again!

Closed 2022-12-29.

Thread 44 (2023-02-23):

Wrong units of measure

pyzimmer, 2023-02-23:
Hello,
Some units of measure are wrong :
- VMC Total Energy Saving is in KWh (not in Wh)
- Fan Duty are in % (not in rpm)

Here is the right config :

```
mqtt:
  sensor:
    # Consumption
    - name: "VMC Power Current"
      state_topic: "comfoair/power_consumption_current"
      unit_of_measurement: W
    - name: "VMC Total Energy Saving"
      state_topic: "comfoair/ah_ytd"
      unit_of_measurement: KWh

    # FAns
    - name: "VMC Exhaust Fan Speed"
      state_topic: "comfoair/exhaust_fan_speed"
      unit_of_measurement: rpm
    - name: "VMC Supply Fan Speed"
      state_topic: "comfoair/supply_fan_speed"
      unit_of_measurement: rpm
    - name: "VMC Exhaust Fan Duty"
      state_topic: "comfoair/exhaust_fan_duty"
      unit_of_measurement: "%"
    - name: "VMC Supply Fan Duty"
      state_topic: "comfoair/supply_fan_duty"
      unit_of_measurement: "%"
    - name: "VMC Supply Fan User Speed"
      state_topic: "comfoair/fan_speed"

      # FLOW
    - name: "VMC Exhaust Fan Flow"
      state_topic: "comfoair/exhaust_fan_flow"
      unit_of_measurement: "m³/h"
    - name: "VMC Supply Fan Flow"
      state_topic: "comfoair/supply_fan_flow"
      unit_of_measurement: "m³/h"

    # TEMPS
    - name: "VMC Outdoor Air Temperature"
      state_topic: "comfoair/outdoor_air_temp"
      unit_of_measurement: "°C"
    - name: "VMC Exhaust Air Temperature"
      state_topic: "comfoair/exhaust_air_temp"
      unit_of_measurement: "°C"
    - name: "VMC Extract Air Temperature"
      state_topic: "comfoair/extract_air_temp"
      unit_of_measurement: "°C"
    - name: "VMC Post Heater Temp Before"
      state_topic: "comfoair/post_heater_temp_before"
      unit_of_measurement: "°C"
    - name: "VMC Post Heater Temp After"
      state_topic: "comfoair/post_heater_temp_after"
      unit_of_measurement: "°C"

    # Humidity
    - name: "VMC Outdoor Air Humidity"
      state_topic: "comfoair/outdoor_air_humidity"
      unit_of_measurement: "%"
    - name: "VMC Exhaust Air Humidity"
      state_topic: "comfoair/exhaust_air_humidity"
      unit_of_measurement: "%"
    - name: "VMC Extract Air Humidity"
      state_topic: "comfoair/extract_air_humidity"
      unit_of_measurement: "%"
    - name: "VMC Supply Air Humidity"
      state_topic: "comfoair/supply_air_humidity"
      unit_of_measurement: "%"
```

vekexasia, 2023-04-15:
:+1:

Closed 2023-06-06.

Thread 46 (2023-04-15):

Project direction and new features

vekexasia, 2023-04-15:
After this project has been released it entered a sleep state. Project seemed mature enough to not get new updates.

Due to the currently opened number of issues which include #43 #45 #25 #26 as well as #32 and others. It looks to me that it was about time to invest some free time to get this project a little love.

Of course if you want to donate me some beer which is the fuel of developers I will always appreciate that.

Anyways. I'm working on getting this on a properly designed lowcost PCB, as soon as I get the PCB delivered and get to test it out i'll also migrate the project to ESPHOME (which someone mentioned on issue #31).

I ordered 15 pcbs, assuming the pcb design works I can ship others to anyone interested in getting it.

This is a preview of the PCB
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

It does measure 45x23mm which is pretty small. The only missing part is an M5Stack Atom Lite ESP32 board. I decided to design it that way cause I did want to keep cost low, and leverage modularity. If ESP32 dies you can always replace it with another M5Stack.

Since the board is very simple and modular it could be designed so that it scales vertically. so, If someone wants some extra functionality such as an ethernet HAT, a design could be made to meet it that needs.

Cheers

vekexasia, 2023-04-28:
project has been converted to esphome enjoy all :) IF you need a custom pcb i've some spare

svde, 2023-05-01:
> project has been converted to esphome enjoy all :)

Excellent choice.

nebman, 2023-05-03:
Excellent, thank you very much!
For anyone else upgrading their ESPs please notice, that the GPIO pins changed.

svde, 2023-05-03:
Would be nice to make the GPIO pins configurable.

vekexasia, 2023-05-03:
@svde yeah i thought about that too. But i think gpio 25 and 21 are almost always available in all boards so I didn't see much of a need letting the pin configurable.

vekexasia, 2023-05-03:
also for everyone who wants i can ship the board with components (not soldered)

svde, 2023-05-03:
People could also choose to DIY with an ESP8266, where pins 21 and 25 aren't available...

nebman, 2023-05-03:
@svde but ESP8266 doesn't have a CAN controller onboard, only ESP32

svde, 2023-05-03:
I thought that we just use GPIO pings on the ESP32 for RX & TX.

Not the built-in CAN controller on the ESP32.

vekexasia, 2023-05-03:
Exactly.

The internal canbus from esp32 is not compatible as far as I know with
extended ids.

Btw svde i think adding custom pins to conf is pretty easy. Ill check if I
have time in the following days

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

wiljums, 2023-05-11:
> also for everyone who wants i can ship the board with components (not soldered)

What would be the cost for the board and shipment to the Netherlands?

vekexasia, 2023-05-11:
about 55€ shipped with all components.

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

--

Andrea Baccega
[image: ***@***.***
[image: ***@***.***
[image: Personal site] <http://www.andreabaccega.com/> [image: Linkedin
Profile] <http://it.linkedin.com/in/andreabaccega> [image: Facebook]
<https://www.facebook.com/andrea.baccega> [image: Google+]
<https://plus.google.com/109217393200753135791> [image: Twitter]
<http://twitter.com/veke87> [image: StackOverflow]
<http://stackoverflow.com/users/314407/andrea-baccega> [image: GitHub]
<https://github.com/vekexasia>

wiljums, 2023-05-11:
Is it also possible to ship it soldered?

Op do 11 mei 2023 om 16:00 schreef Andrea ***@***.***>:

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

vekexasia, 2023-05-22:
sorry for late reply @wiljums. Yes i do have one test board. It is not perfectly soldered so i wouldn't vouch for it. My suggestion would be to solder this yourself juist to make sure things are soldered properly. I'm not a good one :)

jhornych, 2023-07-06:
I guess there is CAN module available including the ESP32 from m5stack, which you are using anyway just for 22EUR, or am I wrong? [M5STACK CAN module](https://shop.m5stack.com/products/atom-canbus-kit-ca-is3050g)

fuatakgun, 2023-10-22:
Looking forward to hear more on this

zweefan, 2023-10-23:
I have soldered the unit for myself and created 4 extra units. I will sell the units. I you are interested please send me a direct message. RegardsStephanOp 22 okt. 2023 om 23:03 heeft Fuat Akgün ***@***.***> het volgende geschreven:
Looking forward to hear more on this

—Reply to this email directly, view it on GitHub, or unsubscribe.You are receiving this because you are subscribed to this thread.Message ID: ***@***.***>

wiljums, 2023-10-23:
> I have soldered the unit for myself and created 4 extra units. I will sell the units. I you are interested please send me a direct message. RegardsStephanOp 22 okt. 2023 om 23:03 heeft Fuat Akgün ***@***.***> het volgende geschreven:  Looking forward to hear more on this —Reply to this email directly, view it on GitHub, or unsubscribe.You are receiving this because you are subscribed to this thread.Message ID: ***@***.***>

Hi zweefan, I am interested and figuring out how to send you a direct message.

Closed 2023-04-28.

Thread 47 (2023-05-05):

Bootloop after flashing the ESPHome version

SkullboyNL, 2023-05-05:
I am trying to flash the ESPHome version, but then the ESP enters a boot loop. I've tried different configurations, but it's still stuck in the bootloop.
The error i get after flashing:
```
01:49:05]E (10278) task_wdt: Task watchdog got triggered. The following tasks did not reset the watchdog in time:
[01:49:05]E (10278) task_wdt:  - loopTask (CPU 1)
[01:49:05]E (10278) task_wdt: Tasks currently running:
[01:49:05]E (10278) task_wdt: CPU 0: IDLE
[01:49:05]E (10278) task_wdt: CPU 1: CAN_LORX
[01:49:05]E (10278) task_wdt: Aborting.
[01:49:05]
[01:49:05]abort() was called at PC 0x400ef275 on core 0
[01:49:05]
[01:49:05]
[01:49:05]Backtrace:0x400836b5:0x3ffbea2c |<-CORRUPTED
WARNING Found stack trace! Trying to decode it
WARNING Decoded 0x400836b5: panic_abort at /Users/ficeto/Desktop/ESP32/ESP32S2/esp-idf-public/components/esp_system/panic.c:402
```

Current yaml:
```
esphome:
  name: air-11

esp32:
  board: nodemcu-32s
  framework:
    type: arduino

# Enable logging
logger:

# Enable Home Assistant API
api:
  password: "gfhgfhgshbhbdbvfdg3354dsgf"

wifi:
  ssid: "*****"
  password: "******"

external_components:
  - source: github://vekexasia/comfoair-esp32
    components: [ comfoair ]

comfoair:
```

Am I doing something wrong or am I missing another configuration line?

vekexasia, 2023-05-06:
hey, can you take a picture of wiring?

SkullboyNL, 2023-05-06:
I first tried without the can module, so only a separate ESP32. Then tried with the can module connected TX to GPIO21 and RX to GPIO25 not yet connected to the comfoair but still the same error message.

Does the ESP not start if the ESP does not receive a signal from the comfoair?

lskuba, 2023-05-19:
I have the same problem after I am adding below to my yaml:
`external_components:
  - source: github://vekexasia/comfoair-esp32
    components: [ comfoair ]

comfoair:`

TroLoos, 2023-05-21:
Same here, wanted to switch to ESPHome and it does go into a bootloop.

`[C][ota:469]: There have been 0 suspected unsuccessful boot attempts.
[D][esp32.preferences:114]: Saving 1 preferences to flash...
[D][esp32.preferences:143]: Saving 1 preferences to flash: 0 cached, 1 written, 0 failed
[I][app:029]: Running through setup()...
E (10347) task_wdt: Task watchdog got triggered. The following tasks did not reset the watchdog in time:
E (10347) task_wdt:  - loopTask (CPU 1)
E (10347) task_wdt: Tasks currently running:
E (10347) task_wdt: CPU 0: IDLE
E (10347) task_wdt: CPU 1: CAN_LORX
E (10347) task_wdt: Aborting.

abort() was called at PC 0x400f9a98 on core 0

Backtrace:0x400836dd:0x3ffbea2c |<-CORRUPTED`

My setup is: ESP32 DEVKIT V1 with SN65HVD230, CAN module connected TX -> G25, RX -> G21 (I also tried G4 and G5 from previous MQTT version - BTW, what should it be?).

My YAML is as follows:

`esphome:
  name: comfoairv2
  friendly_name: comfoairv2

esp32:
  board: esp32doit-devkit-v1
  framework:
    type: arduino

external_components:
  - source: github://vekexasia/comfoair-esp32
    components: [ comfoair ]

logger:
  level: DEBUG

api:
  encryption:
    key: "*REDACTED*"

ota:
  password: "*REDACTED*"

wifi:
  ssid: !secret wifi_ssid
  password: !secret wifi_password

  ap:
    ssid: "Comfoairv2 Hotspot"
    password: "*REDACTED*"

captive_portal:

comfoair:`

vekexasia, 2023-05-21:
That is strange can you share how you wired the board and which board it is?

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

TroLoos, 2023-05-22:
> That is strange can you share how you wired the board and which board it is?
> […](#)

Well, I have exactly this board:

https://botland.com.pl/moduly-wifi-i-bt-esp32/8893-esp32-wifi-bt-42-platforma-z-modulem-esp-wroom-32-zgodny-z-esp32-devkit-5904422337438.html

with Waveshare CAN controller:

https://botland.com.pl/magistrala-can/6960-modul-z-interfejsem-can-sn65hvd230-waveshare-3945-5904422300715.html

As I mentioned - I tried to connect TX to G4 and RX to G5 (from previous setup with MQTT), and also according to new guide TX to G25 and RX to G21 - none work correctly. As far as I can tell - wiring was all right because it worked fine with MQTT version.

I actually just ordered another CAN module to check if the problem might be there, and also AZDelivery D1 Mini NodeMCU ESP32 to be as much compliant with the guide as possible. I will check it out on Wednesday and let you know the result.

vekexasia, 2023-05-22:
CAn you have a try right now?

vekexasia, 2023-05-22:
Apparently there was some recent changes in esp32_can which apparently introduced some issues. I needed to rollback to a prev commit.

Possibly related to https://github.com/collin80/esp32_can/issues/47

SkullboyNL, 2023-05-22:
It is working now thankyou.

TroLoos, 2023-05-23:
What a great support, thank you! Awesome project @vekexasia.

Closed 2023-05-22.

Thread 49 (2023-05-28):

Custom PCB - missing CPL file

dan-s-github, 2023-05-28:
Thanks for making this project available, I ordered the KNX Interface and discovered that a lot of information that is available on the LAN Interface is missing. So this would be a perfect addition to my current system

I like the custom pub design and think this could also be used for other can based integrations.

Went to https://jlcpcb.com to order a set of fully assembled boards.

To order the fully assembled board I first uploaded the Gerber ZIP file and after activating and confirming PCB Assembly
a popup opens which requires to file to be uploaded

- BOM File
- CPL File

The BOM file is currently present in the repo but the CPL file is missing, is this also available or is there another way to get a fully assembled board?

dan-s-github, 2023-06-06:
ordered one of those to see if it would also work

https://shop.m5stack.com/products/atom-canbus-kit-ca-is3050g

vekexasia, 2023-06-06:
wow.. didnt see it. it would have been nice to have it would've spared somuch time :D

dan-s-github, 2023-06-06:
just missing the 12V to 5V converter which you added

vekexasia, 2023-06-06:
Ah. thne it's not good for me :D

dan-s-github, 2023-06-06:
can you add the full schematics of your custom pub to the repo for completeness?

vekexasia, 2023-06-06:
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

JoooostB, 2023-10-09:
@dan-s-github Did you manage to get a CPL file? Or have you walked the manual route?

Closed 2024-03-11.

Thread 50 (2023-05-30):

Missing Controls entities in ESPHome integration

lskuba, 2023-05-30:
I have followed instructions from README and after fixing problem with boot loop I was I able to read sensor entities, thank so much for that.

But I am missing controls entities to e.g. change temperature or fan speed.

I guest this is because of missing ClimateTraits clime controller, so it should be added into C code, or I am  not understanding something?

SkullboyNL, 2023-05-31:
You can use the service called: comfoair_send_command

```
The component exposes 2 services.

comfoair_send_command
comfoair_send_hex
NOTE: the prefix could differ depending on your esphome device name.

comfoair_send_command: allows one "command" parameter. The value of the param can be one of the following pre-bundled commands:

ventilation_level_0
ventilation_level_1
ventilation_level_2
ventilation_level_3
boost_10_min
boost_20_min
boost_30_min
boost_60_min
boost_end
auto
manual
bypass_activate_1h
bypass_deactivate_1h
bypass_auto
ventilation_supply_only
ventilation_supply_only_reset
ventilation_extract_only
ventilation_extract_only_reset
temp_profile_normal
temp_profile_cool
temp_profile_warm
```

marivo, 2023-06-04:
Hello all! Finally, I had time to to get this nice project up and running on my D1 ESP32 mini board, The HA now receives the data from the my Q350 and it has also discovered the two services that I can access under the Developer Tools tab to send commands. However, I am not so experienced with HA to immediately grasp how to set up this beautiful Dashboard that is shown on the main page of the project. Could someone please (!) provide some direction how to get this Dashboard done? Thanks a lot!

marivo, 2023-06-05:
Well, now I got behind the Dashboards in HomeAssitant and see how to create them. It would however take a lot of time to create something similar that Andrea already did. @Andrea:Would it be possible to share the HomeAssistant Dashboard code here such that we can adapt and use it without too much of hassle? That would be great!

JBN164, 2023-06-05:
Thanks a lot @vekexasia for your work, it works perfect. But...
I used the entity card to call a service, e.g. send the command to set the fan speed.
This way I need one card per fan speed. Smarter it would be to define the command in a dropdown and send this value with the call service option. Has anyone an idea to build something like that.

marivo, 2023-06-05:
> Thanks a lot @vekexasia for your work, it works perfect. But... I used the entity card to call a service, e.g. send the command to set the fan speed. This way I need one card per fan speed. Smarter it would be to define the command in a dropdown and send this value with the call service option. Has anyone an idea to build something like that.

This is what also I mentioned in the last post of mine above... In other words, as up to now, anyone who wants to fully integrate the Q350 ventilation system into HA using the Andrea's code needs to build his/her own Dashboard from the scratch. This can be done, of course, there are plenty of GUIs, including the dropdown menues etc, pp. But that would cost time that I personally unfortunately do not have right now...

It would be therefore just great if someone who already created a control Dashboard for this project in HA would just share the contents of the corresponding HA yaml file... Anyone, please?

nebman, 2023-06-05:
I used this code in esphome to define some buttons and a very basic dropdown select field, but I'm sure there is a better way without using lambdas and an id. They will automatically show up in HA as new entities.

```
comfoair:
  id: comfo

button:
  - platform: template
    name: "Comfoair Boost 10m"
    id: comfoair_boost_10min
    on_press:
      then:
        - lambda: |-
            id(comfo).send_command("boost_10_min");

select:
  - platform: template
    name: "Comfoair Stufe"
    id: comfoair_level
    optimistic: true
    options:
      - "Abwesend"
      - "Stufe 1"
      - "Stufe 2"
      - "Stufe 3"
    set_action:
      - lambda: |-
          if (x == "Stufe 1") {
            id(comfo).send_command("ventilation_level_1");
          }
          if (x == "Stufe 2") {
            id(comfo).send_command("ventilation_level_2");
          }
          if (x == "Stufe 3") {
            id(comfo).send_command("ventilation_level_3");
          }
          if (x == "Abwesend") {
            id(comfo).send_command("ventilation_level_0");
          }
```

marivo, 2023-06-19:
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

Today I had time to play around with your Lovelace code and noticed that  binary_sensor.lueftung_stufe_0,  binary_sensor.lueftung_stufe_1,  binary_sensor.lueftung_stufe_2 and  binary_sensor.lueftung_stufe_3 need further definitions. Would it be possible to post the definitions here? Thanks!

JBN164, 2023-06-20:
> Today I had time to play around with your Lovelace code and noticed that binary_sensor.lueftung_stufe_0, binary_sensor.lueftung_stufe_1, binary_sensor.lueftung_stufe_2 and binary_sensor.lueftung_stufe_3 need further definitions. Would it be possible to post the definitions here? Thanks!

I defined the binary sensors for changing color of the fan icon to show the current level.
I wrote this in the configuration.yaml:

````
template:
    - binary_sensor:
        - name: "Lueftung_Stufe_0"
          unique_id: "Lueftung_Stufe_0"
          state: "{{ is_state('sensor.zehnder_lueftung_fan_speed','0') }}"
  
        - name: "Lueftung_Stufe_1"
          unique_id: "Lueftung_Stufe_1"
          state: "{{ is_state('sensor.zehnder_lueftung_fan_speed','1') }}"
  
        - name: "Lueftung_Stufe_2"
          unique_id: "Lueftung_Stufe_2"
          state: "{{ is_state('sensor.zehnder_lueftung_fan_speed','2') }}"
  
        - name: "Lueftung_Stufe_3"
          unique_id: "Lueftung_Stufe_3"
          state: "{{ is_state('sensor.zehnder_lueftung_fan_speed','3') }}"

Peeka49, 2023-07-11:
Really nice card I tried your code but I'm missing some info on the card, Bypass info, filter info, remote info, are unknown. Do you know why I'm missing those info?

Thanks for all the work.

marivo, 2023-07-11:
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

At least in my case, this information appears with time passing after restart. However, you may need switch off and on the Q350 so that the software can properly initialize the variables that are missing in your example. The lack of information in your example is not the problem of the software, imho.

Peeka49, 2023-07-13:
Thanks Marivo, all info are now displayed after rebooting the Q350. Remaining problem is when trying to select fan speed, I have this error message: "failed to call service esphome/comfoair_comfoair_select. connection lost"

Any idea on why it is not working?

Thanks for your help.

marivo, 2023-07-13:
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

That is strange. I have not tried manual fan selection speed yet, since switching auto-manual works fine for me and makes me happy. Maybe Andrea can provide a hint for the error you have?

vekexasia, 2024-03-11:
Hello all sorry for late reply.- Seems like you encountered some kind of integration bug between HA and esphome component?

I regularly use the fan speed control in my dashboard with no problem

marivo, 2024-03-12:
> Hello all sorry for late reply.- Seems like you encountered some kind of integration bug between HA and esphome component?
>
> I regularly use the fan speed control in my dashboard with no problem

Dear Andrea, thanks a lot anyway. Could you please tell me what is the best way to install your plugin in the HA? Via the HACS? The thing is that if I just change the esphome config file I see the component in the HomeAssistant but no GUI that you display on the main page of the GitHub.

vekexasia, 2024-03-13:
There is no UI provided with this project. But there is a doc folder with
some sample yaml you can check.

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

marivo, 2024-03-16:
I get it. Could not try it yet, but may be a quick question before I get to it... Will I get the same appearance as depicted on your github main page (screenshot below) ?

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

vekexasia, 2024-03-16:
Yeah more or less.

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

marivo, 2024-03-20:
Hi Andrea, just compiled the new firmware according to the example comfoair.yaml file from the repository. I cannot see any of the appearance as above on the HomeAssistant main webpage. I think it is because the screenshot that I have put above is actually a manually created  Lovelace graphical interface. Is that true? If yes, would it be possible to share the Lovelace code here so that we can reproduce exactly the same appearance (which I like a lot :))?

marivo, 2024-03-25:
Please...

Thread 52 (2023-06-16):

auto mode not available

J1Buskens, 2023-06-16:
Hi I just upgraded to the ESPHOME version.
When I send the command 'auto' the unit doesn't seem to respond.
I am able to set other settings like e.g. : 'ventilation_level_3'.
I have used the old version with mqtt communication and there the auto command was working.

KrisDeWilde, 2023-11-13:
I have the same issue. Send command 'auto' doesn't respond. Everyting else works fine.

vekexasia, 2024-03-11:
which comfo unit do you have?

J1Buskens, 2024-03-11:
> which comfo unit do you have?

Comfoair Q350

vekexasia, 2024-03-11:
Can you try to set ventilation speed manually to 0. Wait for a bit till reported fan rpm in your dashboard is visibly lower and then switch to auto?

Does it modify the fan speeds?

KrisDeWilde, 2024-03-21:
Hello, my device is a Comfoair Q450.

I tried your suggestion (manual to 0 then to automatic) and it works.

I have to say that my original hardware configuration wasn't the best. I used a Velleman kit to reduce the unit's voltage to 3.3 V. After a few weeks it started missing a lot of values   and the unit disabled the CAN bus. After a few resets I started debugging my hardware and I discovered that the gnd of the device and the ground of the ESP were not quite the same, I saw a diode between them.
Later I fitted a separate USB power supply and connected the device ground to the ESP ground. Now it has been working like a charm for almost 3 months.

Thanks again for this great work!!

Maybe an idea for other users:
I have set my unit to always respond to moisture, even if it is not set to automatic. This causes the device to run at a higher speed when someone takes a bath.

vekexasia, 2024-07-02:
I am interested in the moisture trick. Are u using an external sensor or data from internal humidity as  input?

KrisDeWilde, 2024-07-02:
It is just a setting in the unit. You can set the response for humidity to:
-"not"
-"only on auto"
-"always"
I´m not sure all unit have this sensor, but mine does. When it responds to humidity, the air-flow increases.
Depending on what current ventilation level:
In my case:
- level 1 goes from 165m³ to 255m³
- level 2 goes from 320m³ to 400m³
- level 3 is already max, so no change here.
I suggest level 2 as starting point, this responds very quickly. Level 1 is very slow (more the 10 min delay)
A made a link with the bathroom light, the unit is on level 2 when the light is on.

vekexasia, 2024-07-02:
Very interesting. which unit do u have ?

KrisDeWilde, 2024-07-04:
Zehnder Comfoair Q450

Tigerstrength, 2024-10-28:
First let me thank you @vekexasia! I use this integration to control my Q450 with great success. Only thing I miss is the option to set iT to auto mode and to set the fans to any percent (0-100%) bases on the actual needs.

I think the 0-100% fans are complicated to achieve as that requires emulating the option box, but is there any change we can ‘repair’ the fact that auto mode is not working? I read that it was working in the mqtt version? Any hint about what to send to the unit to get it on automode?

jvanoverveldt, 2024-11-09:
I use this esphome setup with my Q450. When sending out the "auto" command the log gives this output:

`[09:04:06][W][component:237]: Component api took a long time for an operation (1002 ms).`
`[09:04:06][W][component:238]: Components should block for at most 30 ms.`

The unit is never set to "auto" even after setting ventilation_level_0 and waiting for some time.

When sending "ventilation_level_x"

``[09:13:51][W][component:237]: Component api took a long time for an operation (1004 ms).
[09:13:51][W][component:238]: Components should block for at most 30 ms.
[09:13:51][D][sensor:094]: 'fan_speed': Sending state 0.00000  with 0 decimals of accuracy
[09:13:51][D][comfoair.component:244]: ibua fan_speed 0.000000
[09:13:51][D][climate:396]: '' - Sending state:
[09:13:51][D][climate:399]:   Mode: HEAT
[09:13:51][D][climate:404]:   Fan Mode: OFF
[09:13:51][D][climate:419]:   Current Temperature: 18.90°C
[09:13:51][D][climate:425]:   Target Temperature: 23.00°C
[09:13:51][D][climate:428]:   Current Humidity: 55%
[09:13:51][W][component:237]: Component comfoair took a long time for an operation (91 ms).
[09:13:51][W][component:238]: Components should block for at most 30 ms.
``
And the state is set correctly

@vekexasia What is the reason it could work when setting it to zero first?

vekexasia, 2024-11-09:
@jvanoverveldt so setting vent level to zero and then sending auto works?

jvanoverveldt, 2024-11-09:
No, i was not able to use the workaround of setting the ventilation level to 0. That's the reason that i'm trying to understand the logic behind the trick.

pippolino79, 2025-01-31:
Hi, I think I discovered the problem with the AUTO mode:

the "comfoair_operating_mode" has 3 possible states:
- limited_manual
- unlimited_manual
- auto

When you are for example in state "auto" at "speed 1" and you decide to issue command "ventilation_level_2" comfoair swaps speed to level 2 but also swaps mode to "limited_manual".
I guess this is a mode in which after a while the state returns to "auto".

Now the issue/bug:
It is NOT POSSIBLE to go from "limited_manual" directly to "auto" by sending the "auto" command, I don't know why but it is so.
You need first go from "limited_manual" to "unlimited_manual" by issuing the "manual" and then you can go to "auto".

You can try the NON working sequence of commands when you're in auto:
- ventilation_level_2 (goes to state limited_manual)
- auto (remains in state limited_manual)

While this sequence works:
- ventilation_level_2 (goes to state limited_manual)
- manual (goes to state unlimited_manual)
- auto (goes to auto)

Clearly the second working sequence  is not intuitive, if I push AUTO it should go to AUTO and not hafo to go to manual before!!!

I hope this helps to fix the question...

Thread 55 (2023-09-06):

Unknown entity state after restart.

SzymaneKwr, 2023-09-06:
Hello, I have a question about the entity state after ESP reset. All entities are in an unknown state until they are replaced or updated. Is there any way to make entities show their current state after a reset/update?
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

xhess, 2023-09-06:
Thank you for asking this question. I have got the same problem. I think I know what the problem is and that currently there is no solution in this code. As I understand that comfoair-esp32 just listens for messages on the can-bus. The ventilation unit only sends the values when they change. A quick "fix" would be to restart the ventilation unit or you wait until the value changes...

While writing this comment there is currently the possibility to send raw hex commands like described below.

But a real solution would be that the esp32 could ask the ventilation unit for some/all sensor values like described here:
https://github.com/michaelarnauts/comfoconnect/blob/master/PROTOCOL-RMI.md#general-commands

> This command reads a single property identified by the Unit, SubUnit and Property Id. Each writable property may have a definitionrange & recommended step size which are also accesible
> The syntax is: 01 UnitId SubUnitId GetType PropertyId The answer is depended on the type of the property and the GetType. If the value, range and step (everything) is requested, the answer is: Value, lower boundry of range, upper boundry of range, step size.

The ESP could know that there are unknown values and ask specific for these or it could ask for all values.

albertofralbe, 2024-06-17:
Hi, I was wondering if this issue has already been addressed by someone? If so, would you mind to share? Thanks

vekexasia, 2024-06-17:
Hey all,

as far as I know nobody addressed this. tbh i still struggle to understand the usecase of this. I've mine up and running for weeks and apart from esphome updates my esp32 never reboots... maybe some of you cuts power to their VMC unit?

vekexasia, 2024-07-02:
Can u guys let me know if this is working for u?

albertofralbe, 2024-07-02:
Where is the PDOID list?

vekexasia, 2024-07-02:
> Where is the PDOID list?

https://github.com/vekexasia/comfoair-esp32/blob/master/components/comfoair/__init__.py#L26

Also can u please take a look @ https://github.com/vekexasia/comfoair-esp32/issues/74 I am trying to build a compatibility list

Closed 2024-07-04.

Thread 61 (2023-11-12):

_builtin.h:36:10: fatal error: freertos/FreeRTOS.h:

HAUSER3, 2023-11-12:
INFO ESPHome 2023.10.6
INFO Reading configuration /config/esphome/comfoair.yaml...
INFO Detected timezone 'Europe/Berlin'
INFO Generating C++ source...
INFO Compiling app...
Processing comfoair (board: esp01_1m; framework: arduino; platform: platformio/espressif8266@3.2.0)
--------------------------------------------------------------------------------
HARDWARE: ESP8266 80MHz, 80KB RAM, 1MB Flash
Library Manager: Installing SPI @ 2.0.0
Warning! Could not find the package with 'SPI @ 2.0.0' requirements for your system 'linux_x86_64'
Dependency Graph
|-- ESPAsyncTCP-esphome @ 2.0.0
|-- ESPAsyncWebServer-esphome @ 3.1.0
|-- DNSServer @ 1.1.1
|-- ESP8266WiFi @ 1.0
|-- ESP8266mDNS @ 1.2
|-- noise-c @ 0.1.4
|-- ArduinoJson @ 6.18.5
|-- can_common @ 0.3.0+sha.07605a2
|-- ESP32_CAN @ 0.2.5+sha.0fb9878
Compiling .pioenvs/comfoair/src/esphome/components/comfoair/comfoair.cpp.o
Compiling .pioenvs/comfoair/src/esphome/components/esp8266/gpio.cpp.o
Compiling .pioenvs/comfoair/src/esphome/components/esp8266/preferences.cpp.o
Compiling .pioenvs/comfoair/src/esphome/components/homeassistant/time/homeassistant_time.cpp.o
In file included from .piolibdeps/comfoair/esp32_can/src/esp32_can.h:1,
                 from src/esphome/components/comfoair/comfoair.h:2,
                 from src/esphome/components/comfoair/comfoair.cpp:1:
.piolibdeps/comfoair/esp32_can/src/esp32_can_builtin.h:36:10: fatal error: freertos/FreeRTOS.h: No such file or directory
   36 | #include "freertos/FreeRTOS.h"
      |          ^~~~~~~~~~~~~~~~~~~~~
compilation terminated.
*** [.pioenvs/comfoair/src/esphome/components/comfoair/comfoair.cpp.o] Error 1
========================== [FAILED] Took 1.87 seconds ==========================

vekexasia, 2024-03-11:
I cannot replicate.

Closed 2024-03-11.

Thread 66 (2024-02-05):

Error in communication after connecting ESP to ComfoAir (wont even start)

K3iVi, 2024-02-05:
I used standard ESP, but dc stepdown is LM2596. Other than that is everything by manual. ESP is recognized in HA. But when I connect it to Comfoair there is an error of communication. When I try to restart it do not even boot, I have to disconnect 12V from Comfo to stepdown module in order to comfoair to start normally.
Double check with multimeter and stepdown module is on 3,3V output voltage.
I am also using comfosense-c55 module, but when I disconnect that it still not working only with ESP.

Can be some overcurrent on comfoair or something? Or I missed something?
I will try external power supply for esp.

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

vekexasia, 2024-02-05:
I doubt it might be an overcurrent protection tbh. if esp32 does not boot then it might be 3.3 is not stable and it goes in brownout detection.

A short could also explain it but i can't see it from this pic. U sure your board has 3v3 on that vcc pin? I see a voltage regulator on that module so maybe that is +5v?

K3iVi, 2024-02-05:
ComfoAir unit won't start up after restart when EPS is connected to the ComfoAir board, thas is the problem. I have to unplug 12V from the board to get it working again. I triple checked wiring... Stepdown is set to 3,3V checked with multimeter. Connected to ESP to 3.3V.
Should I increase voltage? Or any other guesses?

nebman, 2024-02-05:
Double check the ESP side CAN_RX and CAN_TX pins, I had the same behaviour when the default pins changed, probably blocks the bus otherwise

K3iVi, 2024-02-07:
Thank you :) this was it. I had the connection right but by a different/wrong scheme where it was connected to D4/D5. But it should be to 21 and 25. Reconnected and works.

vekexasia, 2024-03-11:
Glad to hear it worked @K3iVi closing this issue

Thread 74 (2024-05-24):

Showcase Ur setup and compatibility list

vekexasia, 2024-05-24:
Hello, it would be nice if people share their setup and their comfo machine model number so I can keep track of the project compatibility list.

hb0nes, 2024-10-28:
I made this work with my Q350, with a LilyGo TCAN-485.
I am a complete newb, but somehow managed anyway after some trial & error with a board that wasn't listed on this repo.
I thought it might help others.

I:
- wired the GND (black) from the Q350 to both CAN_GND and - for the board.
- wired 12V (red) to +.
- wired Yellow to CAN_H and white to CAN_L.

Added this to ESPHome yaml:

```
# For me, setting these to off made everything work.
switch:
  - platform: gpio
    id: can_se
    pin:
      number: 23
      inverted: false
    name: "can_se"
  - platform: gpio
    id: can_en
    pin:
      number: 16
      inverted: false
    name: "can_en"

external_components:
  - source: github://vekexasia/comfoair-esp32
    components: [ comfoair ]

comfoair:
  id: comfo
  rx_pin: GPIO26
  tx_pin: GPIO27

# Enable Web server
web_server:
  port: 80

button:
  - platform: template
    name: "Boost 10m"
    id: comfoair_boost_10min
    on_press:
      then:
        - lambda: |-
            id(comfo).send_command("boost_10_min");
  - platform: template
    name: "Boost 60m"
    id: comfoair_boost_60min
    on_press:
      then:
        - lambda: |-
            id(comfo).send_command("boost_60_min");
  - platform: template
    name: "Boost End"
    id: comfoair_boost_end
    on_press:
      then:
        - lambda: |-
            id(comfo).send_command("boost_end");

select:
  - platform: template
    name: "Ventilation Level"
    id: comfoair_ventilation_level
    optimistic: true
    options:
      - "Disabled"
      - "Level 1"
      - "Level 2"
      - "Level 3"
    set_action:
      - lambda: |-
          if (x == "Level 1") {
            id(comfo).send_command("ventilation_level_1");
          }
          if (x == "Level 2") {
            id(comfo).send_command("ventilation_level_2");
          }
          if (x == "Level 3") {
            id(comfo).send_command("ventilation_level_3");
          }
          if (x == "Disabled") {
            id(comfo).send_command("ventilation_level_0");
          }
  - platform: template
    name: "Mode"
    id: comfoair_mode
    optimistic: true
    options:
      - "auto"
      - "manual"
    set_action:
      - lambda: |-
          if (x == "auto") {
            id(comfo).send_command("auto");
          }
          if (x == "manual") {
            id(comfo).send_command("manual");
          }
```

jvanoverveldt, 2024-11-09:
I can confirm a working setup with a Q450:

I used these components:
-AZ-Delivery LM2596S Buck DC-DC
-Waveshare SN65HVD230 Can
-AZDelivery NodeMCU ESP32 S (i used this one because it has an external antenna connection)
-external antenna

The configuration is not able to set "auto" mode. I added my insights in #52

My current yaml is:

´´
external_components:
  - source: github://vekexasia/comfoair-esp32
    components: [ comfoair ]

esphome:
  name: zehnder
  friendly_name: zehnder
  min_version: 2024.6.0
  name_add_mac_suffix: false

esp32:
  board: nodemcu-32s
  framework:
    type: arduino

# Enable logging
logger:

# Enable Home Assistant API
api:

# Allow Over-The-Air updates
ota:
- platform: esphome

wifi:
  # Set up a wifi access point
  manual_ip:
    static_ip: 192.168.0.60
    gateway: 192.168.0.1
    subnet: 255.255.255.0
  ssid: !secret wifi_ssid
  password: !secret wifi_password

time:
  - platform: homeassistant
    id: homeassistant_time

# Enable Web server
web_server:
  port: 80

comfoair:
    id: comfo
    rx_pin: GPIO3
    tx_pin: GPIO1

gytisgreitai, 2025-02-07:
https://www.aliexpress.com/item/1005006734943258.html for me doesn't work with this one SN65HVD230. 350Q does not even boot up, and after unplugging gets into safe mode and asks how to boot

Works fine with old usb-to-can adatper though

TriggrHappy, 2025-02-07:
I can confirm this. Only original waveshare worked for me.

> https://www.aliexpress.com/item/1005006734943258.html for me doesn't work with this one SN65HVD230. 350Q does not even boot up, and after unplugging gets into safe mode and asks how to boot
>
> Works fine with old usb-to-can adatper though

gytisgreitai, 2025-02-07:
Where does one buy Waveshare? Directly from them ?

jvanoverveldt, 2025-02-07:
I bought it from Amazon.

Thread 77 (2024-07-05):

Showing up in HA but entity stay in UNKNOWN state

bcornelis, 2024-07-05:
Dear,

I have the following setup:
- Zehnder ComfoAir Q 600 (not listed as compatible in this repo afaik, but expecting it to work)
- Sn65hvd230 Vp230 Can reader: https://nl.aliexpress.com/item/1005006438437964.html
- esp32cam:
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

Following connections are made:
- can RX --> GPIO3
- can TX --> GPIO1
- can H --> blue wire
- can L --> white/blue wire

The esp32 is properly setup in esphome showing up and I see al the entities, but their state is unknown:
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

So their must be something not properly setup. What's the best way to start debugging? Can I enable CAN logging to make sure the connection to the Zehnder device is working?

Thanks!

bcornelis, 2024-07-05:
As extra information, I took the comfo config from following file: https://github.com/vekexasia/comfoair-esp32/blob/master/docs/esphome_sample.yaml, only changing the pin numbers

vekexasia, 2024-07-05:
Can u check the logs and post them here?

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

bcornelis, 2024-07-05:
I restarted the esp32, and then see those logs appear:

`[16:48:01][C][logger:185]: Logger:
[16:48:01][C][logger:186]:   Level: DEBUG
[16:48:01][C][logger:188]:   Log Baud Rate: 115200
[16:48:01][C][logger:189]:   Hardware UART: UART0
[16:48:01][C][mdns:115]: mDNS:
[16:48:01][C][mdns:116]:   Hostname: esphome-web-394a54
[16:48:01][C][esphome.ota:073]: Over-The-Air updates:
[16:48:01][C][esphome.ota:074]:   Address: esphome-web-394a54.local:3232
[16:48:01][C][esphome.ota:075]:   Version: 2
[16:48:01][C][safe_mode:018]: Safe Mode:
[16:48:01][C][safe_mode:020]:   Boot considered successful after 60 seconds
[16:48:01][C][safe_mode:021]:   Invoke after 10 boot attempts
[16:48:01][C][safe_mode:023]:   Remain in safe mode for 300 seconds
[16:48:01][C][api:139]: API Server:
[16:48:01][C][api:140]:   Address: esphome-web-394a54.local:6053
[16:48:01][C][api:144]:   Using noise encryption: NO
[16:48:02][D][comfoair.component:166]: update_next 278 - iterator 31
[16:48:03][D][comfoair.component:166]: update_next 290 - iterator 32
[16:48:04][D][comfoair.component:166]: update_next 291 - iterator 33
[16:48:05][D][comfoair.component:166]: update_next 292 - iterator 34
[16:48:06][D][comfoair.component:166]: update_next 293 - iterator 35
[16:48:07][D][comfoair.component:166]: update_next 294 - iterator 36
[16:48:08][D][comfoair.component:166]: update_next 369 - iterator 37
[16:48:09][D][comfoair.component:166]: update_next 370 - iterator 38
[16:48:10][D][comfoair.component:166]: update_next 371 - iterator 39
[16:48:11][D][comfoair.component:166]: update_next 372 - iterator 40`

vekexasia, 2024-07-05:
This looks like u're not reallly receiving anything on canbus

bcornelis, 2024-07-05:
There are two assumptions:
- I haven't connecties the 12v line as I'm powering the ESP32 through An external 5V power supply
- I haven't enabled anything on the Zehnder tot 'activate' the bus
Are those assumptions correct?

bcornelis, 2024-07-05:
I've solved the issue by not using the RJ45 connector, but using the canbus wires directly. I do get the expected results now:
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

Thanks for your help!

vekexasia, 2024-07-05:
Glad to hear @bcornelis can u also comment on #74 ?

Closed 2024-07-05.

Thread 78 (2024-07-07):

compilation error

saker88, 2024-07-07:
Im getting error and I do not know how to fix this ?

[away_indicator] is an invalid option for [comfoair]. Please check the indentation.

ive tried to rewrite that part , space check and nothing seems to help..

please help :D im blind and lost in fog here.

vekexasia, 2024-07-07:
Hey @saker88 can u share ur config please?

saker88, 2024-07-07:
esp config

`esphome:
  name: comfoair
  friendly_name: comfoair

esp32:
  board: esp32dev
  framework:
    type: arduino

# Enable logging
logger:

# Enable Home Assistant API
api:
  encryption:
    key: "6xoH9BDiFKQT+D9M4PfCufjaH0M7duaJOKlVMqiYlJM="

ota:
  - platform: esphome
    password: "71fcd5be07c55b0dfe28e97cf74d42bb"

wifi:
  ssid: !secret wifi_ssid
  password: !secret wifi_password

  # Enable fallback hotspot (captive portal) in case wifi connection fails
  ap:
    ssid: "Comfoair Fallback Hotspot"
    password: "GymQmucjlJg9"

captive_portal:

external_components:
  - source: github://vekexasia/comfoair-esp32
    components: [ comfoair ]

comfoair:
  id: comfo
  rx_pin: GPIO5
  tx_pin: GPIO4
  supply_fan_speed:
    name: supply_fan_speed
    disabled_by_default: false
    force_update: false
    unit_of_measurement: rpm
    accuracy_decimals: 0
    filters:
      - or:
        - throttle: 300s
        - delta: 100.0
  fan_speed:
    name: fan_speed
    disabled_by_default: false
    force_update: false
    unit_of_measurement: ''
    accuracy_decimals: 0
    filters:
      - throttle: 300s
  next_fan_change:
    name: next_fan_change
    disabled_by_default: false
    force_update: false
    unit_of_measurement: s
    accuracy_decimals: 0
    filters:
      - or:
        - throttle: 300s
        - delta: 180.0
  next_bypass_change:
    name: next_bypass_change
    disabled_by_default: false
    force_update: false
    unit_of_measurement: s
    accuracy_decimals: 0
  exhaust_fan_duty:
    name: exhaust_fan_duty
    disabled_by_default: false
    force_update: false
    unit_of_measurement: '%'
    accuracy_decimals: 0
    filters:
      - or:
        - throttle: 300s
        - delta: 2.0
  supply_fan_duty:
    name: supply_fan_duty
    disabled_by_default: false
    force_update: false
    unit_of_measurement: '%'
    accuracy_decimals: 0
    filters:
      - or:
        - throttle: 300s
        - delta: 2.0
  exhaust_fan_flow:
    name: exhaust_fan_flow
    disabled_by_default: false
    force_update: false
    unit_of_measurement: m³/h
    accuracy_decimals: 0
    filters:
      - or:
        - throttle: 300s
        - delta: 5.0
  supply_fan_flow:
    name: supply_fan_flow
    disabled_by_default: false
    force_update: false
    unit_of_measurement: m³/h
    accuracy_decimals: 0
    filters:
      - or:
        - throttle: 300s
        - delta: 5.0
  exhaust_fan_speed:
    name: exhaust_fan_speed
    disabled_by_default: false
    force_update: false
    unit_of_measurement: rpm
    accuracy_decimals: 0
    filters:
      - or:
        - throttle: 300s
        - delta: 100.0
  power_consumption_current:
    name: power_consumption_current
    disabled_by_default: false
    force_update: false
    unit_of_measurement: W
    accuracy_decimals: 0
    filters:
      - or:
        - throttle: 300s
        - delta: 15.0
  energy_consumption_ytd:
    name: energy_consumption_ytd
    disabled_by_default: false
    force_update: false
    unit_of_measurement: kWh
    accuracy_decimals: 0
  energy_consumption_since_start:
    name: energy_consumption_since_start
    disabled_by_default: false
    force_update: false
    unit_of_measurement: kWh
    accuracy_decimals: 0
  days_remaining_filter:
    name: days_remaining_filter
    disabled_by_default: false
    force_update: false
    unit_of_measurement: days
    accuracy_decimals: 0
  avoided_heating_actual:
    name: avoided_heating_actual
    disabled_by_default: false
    force_update: false
    unit_of_measurement: W
    accuracy_decimals: 2
    filters:
      - throttle_average: 300s
      - filter_out: nan
  avoided_heating_ytd:
    name: avoided_heating_ytd
    disabled_by_default: false
    force_update: false
    unit_of_measurement: Wh
    accuracy_decimals: 0
  avoided_heating_total:
    name: avoided_heating_total
    disabled_by_default: false
    force_update: false
    unit_of_measurement: Wh
    accuracy_decimals: 0
  avoided_cooling_actual:
    name: avoided_cooling_actual
    disabled_by_default: false
    force_update: false
    unit_of_measurement: W
    accuracy_decimals: 2
    filters:
      - or:
        - throttle: 300s
        - delta: 1.0
  avoided_cooling_ytd:
    name: avoided_cooling_ytd
    disabled_by_default: false
    force_update: false
    unit_of_measurement: Wh
    accuracy_decimals: 0
  avoided_cooling_total:
    name: avoided_cooling_total
    disabled_by_default: false
    force_update: false
    unit_of_measurement: Wh
    accuracy_decimals: 0
  bypass_state:
    name: bypass_state
    disabled_by_default: false
    force_update: false
    unit_of_measurement: '%'
    accuracy_decimals: 0
  rmot:
    name: rmot
    disabled_by_default: false
    force_update: false
    unit_of_measurement: °C
    accuracy_decimals: 1
  target_temp:
    name: target_temp
    disabled_by_default: false
    force_update: false
    unit_of_measurement: °C
    accuracy_decimals: 1
  pre_heater_temp_before:
    name: pre_heater_temp_before
    disabled_by_default: false
    force_update: false
    unit_of_measurement: °C
    accuracy_decimals: 1
    filters:
      - or:
        - throttle: 300s
        - delta: 2.0
  post_heater_temp_before:
    name: post_heater_temp_before
    disabled_by_default: false
    force_update: false
    unit_of_measurement: °C
    accuracy_decimals: 1
    filters:
      - or:
        - throttle: 300s
        - delta: 0.3
  extract_air_temp:
    name: extract_air_temp
    disabled_by_default: false
    force_update: false
    unit_of_measurement: °C
    accuracy_decimals: 1
  exhaust_air_temp:
    name: exhaust_air_temp
    disabled_by_default: false
    force_update: false
    unit_of_measurement: °C
    accuracy_decimals: 1
    filters:
      - or:
        - throttle: 300s
        - delta: 0.3
  outdoor_air_temp:
    name: outdoor_air_temp
    disabled_by_default: false
    force_update: false
    unit_of_measurement: °C
    accuracy_decimals: 1
    filters:
      - or:
        - throttle: 300s
        - delta: 0.3
  pre_heater_temp_after:
    name: pre_heater_temp_after
    disabled_by_default: false
    force_update: false
    unit_of_measurement: °C
    accuracy_decimals: 1
    device_class: temperature
    filters:
      - or:
        - throttle: 300s
        - delta: 0.3
  post_heater_temp_after:
    name: post_heater_temp_after
    disabled_by_default: false
    force_update: false
    unit_of_measurement: °C
    accuracy_decimals: 1
    filters:
      - or:
        - throttle: 300s
        - delta: 0.3
  extract_air_humidity:
    name: extract_air_humidity
    disabled_by_default: false
    force_update: false
    unit_of_measurement: '%'
    accuracy_decimals: 0
    filters:
      - or:
        - throttle: 300s
        - delta: 2.0
  exhaust_air_humidity:
    name: exhaust_air_humidity
    disabled_by_default: false
    force_update: false
    unit_of_measurement: '%'
    accuracy_decimals: 0
    filters:
      - or:
        - throttle: 300s
        - delta: 2.0
  outdoor_air_humidity:
    name: outdoor_air_humidity
    disabled_by_default: false
    force_update: false
    unit_of_measurement: '%'
    accuracy_decimals: 0
    filters:
      - or:
        - throttle: 300s
        - delta: 2.0
  pre_heater_hum_after:
    name: pre_heater_hum_after
    disabled_by_default: false
    force_update: false
    unit_of_measurement: '%'
    accuracy_decimals: 0
    filters:
      - or:
        - throttle: 300s
        - delta: 2
  supply_air_humidity:
    name: supply_air_humidity
    disabled_by_default: false
    force_update: false
    unit_of_measurement: '%'
    accuracy_decimals: 0
    filters:
      - or:
        - throttle: 300s
        - delta: 2.0
  away_indicator:
    name: away_indicator
    disabled_by_default: false
  operating_mode:
    name: operating_mode
    disabled_by_default: false
  bypass_activation_mode:
    name: bypass_activation_mode
    disabled_by_default: false
  temp_profile:
    name: temp_profile
    disabled_by_default: false

# see: https://esphome.io/components/time.html
time:
  - platform: homeassistant
    id: homeassistant_time

# Enable Web server
web_server:
  port: 80

button:
  - platform: template
    name: "Boost 10m"
    id: comfoair_boost_10min
    on_press:
      then:
        - lambda: |-
            id(comfo).send_command("boost_10_min");

select:
  - platform: template
    name: "Belüftungsstärke"
    id: comfoair_ventilation_level
    optimistic: true
    options:
      - "Abwesend"
      - "Stufe 1"
      - "Stufe 2"
      - "Stufe 3"
    set_action:
      - lambda: |-
          if (x == "Stufe 1") {
            id(comfo).send_command("ventilation_level_1");
          }
          if (x == "Stufe 2") {
            id(comfo).send_command("ventilation_level_2");
          }
          if (x == "Stufe 3") {
            id(comfo).send_command("ventilation_level_3");
          }
          if (x == "Abwesend") {
            id(comfo).send_command("ventilation_level_0");
          }
  - platform: template
    name: "Mode"
    id: comfoair_mode
    optimistic: true
    options:
      - "auto"
      - "manual"
    set_action:
      - lambda: |-
          if (x == "auto") {
            id(comfo).send_command("auto");
          }
          if (x == "manual") {
            id(comfo).send_command("manual");
          }`

vekexasia, 2024-07-08:
hey can u check this comment here ?  https://github.com/vekexasia/comfoair-esp32/issues/76#issuecomment-2213244441

you do not really need all the other configuration elements now you can specify a global filter like so:

```yaml
comfoair:
  global_filters:
    - throttle: 10s
```

mattapo, 2024-07-08:
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

"away_indicator" is just "away". Edit the yaml file and the error will not appear

vekexasia, 2024-07-08:
hey @mattapo  i already removed all the entries from the sample most people dont need throttling per single sensor https://github.com/vekexasia/comfoair-esp32/blob/8d63d76fc53c933127928f9cec91cd4bae2cf187/docs/esphome_sample.yaml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

saker88, 2024-07-10:
Hey, I managed to solve my issue by omitting the away_indicator and rewriting whole code once more. Now, I need to handle the wiring. I've noticed that you're using the M5Stack Atom (I assume) and in your code, you're referring to GPIO5 and GPIO4. On the PCB, you're connecting to pins G21 and G25. How do these correlate with the ESP32 WROOM dev board? Are they the same, or do I need to redefine them to different pins?

Thanks for updating the sample code and explaining the basics. I'm new to the HA system and YAML, and I'm trying to learn and understand by running shared projects. I appreciate your patience with us "noobs." It's great that even seemingly silly problems or questions don't go unanswered and are addressed in a professional manner.

vekexasia, 2024-07-10:
Hey yes. I am using the custom PCB with the m5stack atom. But the example code was made by another person. You can use the pins you want. If you can choose, checkout the datasheet for where parts are (skip uart0)

Closed 2024-07-16.

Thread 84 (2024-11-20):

Help connecting

AndrewAkinson, 2024-11-20:
Hi, I'm floundering a bit. Just installed HA 2024.11.1 with ESP home 2024.10.3.

I’m trying to connect to a Comfoair Q450

I’ve installed the .yaml on a

https://raw.githubusercontent.com/AchimPieters/esp32-homekit-camera/master/Images/ESP32-30PIN-DEVBOARD.png

(well I think it is that)
```
esphome:
  name: play32a
  friendly_name: Play32A

esp32:
  board: esp32doit-devkit-v1
  framework:
    type: arduino

# Enable logging
logger:

# Enable Home Assistant API
api:
<snip>
ota:
<snip>
wifi:
<snip>

  # Enable fallback hotspot (captive portal) in case wifi connection fails
  ap:

captive_portal:

external_components:
  - source: github://vekexasia/comfoair-esp32
    components: [ comfoair ]

comfoair:
    id: comfo
    rx_pin: GPIO14
    tx_pin: GPIO13

web_server:
  port: 80
  version: 2
  ota: false
```

I’m using usb to power it, as I don’t have a 12V stepdown, I assume that is only for power, so can be replaced by usb power?

I’m using a CAN Bus Transceiver – TJA1051T/3 as it is the one I happen to have! It has a termination switch, that I have tried on and off.

I can add the device to HA dashboard and it shows lots of sensors starting with lay32A analog_input_0_10v_1, but the results are all shown as unknown

Looking at the logs through HA I get the standard connection then it just sits there. Pressing the boot physical boot switch it shows this

```
WARNING play32a @ 192.168.0.112: Connection error occurred: [Errno 104] Connection reset by peer
INFO Processing unexpected disconnect from ESPHome API for play32a @ 192.168.0.112
WARNING Disconnected from API
INFO Successfully connected to play32a @ 192.168.0.112 in 0.007s
INFO Successful handshake with play32a @ 192.168.0.112 in 0.085s
[09:20:54][D][comfoair.component:166]: update_next 218 - iterator 21
[09:20:55][D][comfoair.component:166]: update_next 227 - iterator 22
[09:20:56][D][comfoair.component:166]: update_next 209 - iterator 23
[09:20:57][D][comfoair.component:166]: update_next 212 - iterator 24
[09:20:58][D][comfoair.component:166]: update_next 220 - iterator 25
[09:20:59][D][comfoair.component:166]: update_next 221 - iterator 26
[09:21:00][D][comfoair.component:166]: update_next 274 - iterator 27
[09:21:01][D][comfoair.component:166]: update_next 275 - iterator 28
[09:21:02][D][comfoair.component:166]: update_next 276 - iterator 29
[09:21:03][D][comfoair.component:166]: update_next 277 - iterator 30
[09:21:04][D][comfoair.component:166]: update_next 278 - iterator 31
[09:21:05][D][comfoair.component:166]: update_next 290 - iterator 32
[09:21:06][D][comfoair.component:166]: update_next 291 - iterator 33
[09:21:07][D][comfoair.component:166]: update_next 292 - iterator 34
[09:21:08][D][comfoair.component:166]: update_next 293 - iterator 35
[09:21:09][D][comfoair.component:166]: update_next 294 - iterator 36
[09:21:10][D][comfoair.component:166]: update_next 369 - iterator 37
[09:21:10][D][api:103]: Accepted 192.168.0.100
[09:21:10][D][api.connection:1446]: Home Assistant 2024.11.1 (192.168.0.100): Connected successfully
[09:21:11][D][comfoair.component:166]: update_next 370 - iterator 38
[09:21:12][D][comfoair.component:166]: update_next 371 - iterator 39
[09:21:13][D][comfoair.component:166]: update_next 372 - iterator 40
[09:21:14][D][comfoair.component:166]: update_next 49 - iterator 41
[09:21:15][D][comfoair.component:166]: update_next 66 - iterator 42
[09:21:16][D][comfoair.component:166]: update_next 67 - iterator 43
[09:21:17][D][comfoair.component:166]: update_next 210 - iterator 44
[09:21:18][D][comfoair.component:166]: update_next 211 - iterator 45
[09:21:19][D][comfoair.component:166]: update_next 56 - iterator 46
[09:21:20][D][comfoair.component:166]: update_next 16 - iterator 47
[09:21:21][D][comfoair.component:166]: update_next 70 - iterator 48
[09:21:22][D][comfoair.component:166]: update_next 71 - iterator 49
[09:21:34][I][safe_mode:041]: Boot seems successful; resetting boot loop counter
[09:21:34][D][esp32.preferences:114]: Saving 1 preferences to flash...
[09:21:34][D][esp32.preferences:143]: Saving 1 preferences to flash: 0 cached, 1 written, 0 failed
```

Accessing the webpage states are all NA, I can change from Cool to Heat
```
09:33:10	[D]	[climate:011]	'' - Setting
09:33:10	[D]	[climate:015]	 Mode: HEAT
09:33:11	[W]	[component:237]	Component web_server took a long time for an operation (1028 ms).
09:33:11	[W]	[component:238]	Components should block for at most 30 ms.
```
However the unit is in AUTO and it does not change on the unit.

However, I'm not sure this helps, as if I remove the links between the ESP and the CAN transceiver I get the same results.

So it looks like it is not actually sending/receiving anything, but I do not know how I can trouble shoot this?
Issue #77 seems to have been using the RJ45, but I'm using the push in connectors.
Issue #40 seems to be a broken CAN bus, can this be tested, I only have one of them.

I'm struggling to find a way to proceed, except buy more parts in case they are broken! Any suggestions welcome
thanks
Andrew

AndrewAkinson, 2024-11-20:
Oh that is embarrassing, I had done the standard swap the rx and tx across the two boards as you would if connecting between two esp etc. However in this case the GPIO is listing which to connect to the rx and tx pin not setting them to rx and tx. Anyway data coming in on some of them, now just need to work out how to get that fancy front end,

Closed 2024-11-20.

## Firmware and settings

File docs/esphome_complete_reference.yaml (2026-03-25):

# ============================================================================
# ComfoAir ESP32 - Vollständige Referenz-Konfiguration
# ============================================================================
# Diese Datei zeigt ALLE verfügbaren Parameter und Sensoren
# Angepasst an die tatsächliche generierte Konfiguration
# ============================================================================

esphome:
  name: esp32-comfoair-can-bridge
  friendly_name: ComfoAir Q350 CAN
  name_add_mac_suffix: false

esp32:
  board: esp32dev
  framework:
    type: arduino

logger:
  level: DEBUG

external_components:
  - source:
      type: git
      url: https://github.com/waverider93/comfoair-esp32
      ref: fix/memory-leak-and-optimizations
    components: [comfoair]
    refresh: 1d

api:
  encryption:
    key: !secret api_key
  custom_services: true  # Required for comfoair component (ESPHome 2026.3+)

ota:
  - platform: esphome

wifi:
  ssid: !secret wifi_ssid
  password: !secret wifi_password

# ============================================================================
# COMFOAIR KOMPONENTE - VOLLSTÄNDIGE KONFIGURATION
# ============================================================================
comfoair:
  - id: comfo
    name: "ComfoAir Q350"  # Name für das Climate-Entity (ERFORDERLICH!)
    
    # -------------------------------------------------------------------------
    # CAN-Bus Pins (GPIO-Nummern)
    # -------------------------------------------------------------------------
    tx_pin: 25  # Standard: 25
    rx_pin: 21  # Standard: 21
    
    # -------------------------------------------------------------------------
    # Climate-Entity Visual-Einstellungen (Optional)
    # -------------------------------------------------------------------------
    visual:
      min_temperature: 15 °C
      max_temperature: 30 °C
      temperature_step: 0.5 °C
    
    # disabled_by_default: false  # Alle Entitäten standardmäßig aktiviert
    
    # =========================================================================
    # SENSOREN (Sensor-Plattform)
    # =========================================================================
    
    # -------------------------------------------------------------------------
    # Lüfter-Sensoren
    # -------------------------------------------------------------------------
    fan_speed:
      name: "Lüfterstufe"
      # disabled_by_default: false
      # force_update: false
      # unit_of_measurement: ""
      # accuracy_decimals: 0
    
    exhaust_fan_duty:
      name: "Abluft Lüfter Leistung"
      # unit_of_measurement: "%"
      # accuracy_decimals: 0
    
    supply_fan_duty:
      name: "Zuluft Lüfter Leistung"
      # unit_of_measurement: "%"
    
    exhaust_fan_flow:
      name: "Abluft Volumenstrom"
      # unit_of_measurement: "m³/h"
    
    supply_fan_flow:
      name: "Zuluft Volumenstrom"
      # unit_of_measurement: "m³/h"
    
    exhaust_fan_speed:
      name: "Abluft Lüfterdrehzahl"
      # unit_of_measurement: "rpm"
    
    supply_fan_speed:
      name: "Zuluft Lüfterdrehzahl"
      # unit_of_measurement: "rpm"
    
    # -------------------------------------------------------------------------
    # Timer-Sensoren (nächste Änderung in Sekunden)
    # -------------------------------------------------------------------------
    next_fan_change:
      name: "Nächste Lüfterstufen-Änderung"
      # unit_of_measurement: "s"
    
    next_bypass_change:
      name: "Nächste Bypass-Änderung"
      # unit_of_measurement: "s"
    
    next_supply_change:
      name: "Nächste Zuluft-Änderung"
      # unit_of_measurement: "s"
    
    next_exhaust_change:
      name: "Nächste Abluft-Änderung"
      # unit_of_measurement: "s"
    
    # -------------------------------------------------------------------------
    # Energie-Sensoren
    # -------------------------------------------------------------------------
    power_consumption_current:
      name: "Aktueller Stromverbrauch"
      # unit_of_measurement: "W"
    
    energy_consumption_ytd:
      name: "Energieverbrauch Jahr"
      # unit_of_measurement: "kWh"
    
    energy_consumption_since_start:
      name: "Energieverbrauch Gesamt"
      # unit_of_measurement: "kWh"
    
    # -------------------------------------------------------------------------
    # Wartung
    # -------------------------------------------------------------------------
    days_remaining_filter:
      name: "Tage bis Filterwechsel"
      # unit_of_measurement: "days"
    
    # -------------------------------------------------------------------------
    # Wärmerückgewinnung - Heizung vermieden
    # -------------------------------------------------------------------------
    avoided_heating_actual:
      name: "Vermiedene Heizleistung aktuell"
      # unit_of_measurement: "W"
    
    avoided_heating_ytd:
      name: "Vermiedene Heizenergie Jahr"
      # unit_of_measurement: "kWh"
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

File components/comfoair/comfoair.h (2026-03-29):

#pragma once
#include <esp32_can.h>

#include "esphome/components/api/custom_api_device.h"
#include "esphome/core/component.h"
#include "esphome/components/sensor/sensor.h"
#include "esphome/components/binary_sensor/binary_sensor.h"
#include "esphome/components/text_sensor/text_sensor.h"
#include "esphome/components/climate/climate.h"
#include "esphome/components/climate/climate_mode.h"
#include "esphome/components/climate/climate_traits.h"
#include "CanAddress.h"
#include "commands.h"
#define amin(a,b) ((a) < (b) ? (a): (b))

namespace esphome {
namespace comfoair {

static const char *TAG = "comfoair.component";

template <typename T, typename CONV>
class ComfoSensor {
  public:
    T* sensor;
    float divider;
    CONV conversion;
};

class Comfoair: public Component, public climate::Climate, public esphome::api::CustomAPIDevice {

 public:
  void set_rx(int rx) { rx_ = rx; }
  void set_tx(int tx) { tx_ = tx; }
  void register_sensor(sensor::Sensor *obj, std::string key, int PDOID, int conversionType, int divider) {
    ComfoSensor<sensor::Sensor, int> *cs = new ComfoSensor<sensor::Sensor, int>();
    cs->sensor = obj;
    cs->divider = divider;
    cs->conversion = conversionType;
    sensors[PDOID] = *cs;
    this->PDOs.push_back(PDOID);
    this->PDOsMap[PDOID] = key;
  }
  void register_textSensor(text_sensor::TextSensor *obj, std::string key, int PDOID, std::string (*convLambda)(uint8_t *) ) {
    ComfoSensor<text_sensor::TextSensor, std::string (*)(uint8_t *)> *cs = new ComfoSensor<text_sensor::TextSensor, std::string (*)(uint8_t *)>();
    cs->sensor = obj;
    cs->conversion = convLambda;
    textSensors[PDOID] = *cs;
    this->PDOs.push_back(PDOID);
    this->PDOsMap[PDOID] = key;
  }
  void register_binarySensor(binary_sensor::BinarySensor *obj, std::string key, int PDOID, bool (*convLambda)(uint8_t *) ) {
    ComfoSensor<binary_sensor::BinarySensor, bool (*)(uint8_t *)> *cs = new ComfoSensor<binary_sensor::BinarySensor, bool (*)(uint8_t *)>();
    cs->sensor = obj;
    cs->conversion = convLambda;
    binarySensors[PDOID] = *cs;
    this->PDOs.push_back(PDOID);
    this->PDOsMap[PDOID] = key;
  }
  /**
    * Send a command to the ComfoAir
    * @param command The command to send
    */
  void send_command(std::string command) {
    #define CMDIF(name) if (command == #name) { \
                          std::vector<uint8_t> cmd_data( CMD_ ## name ); \
                          this->sendVector(&cmd_data); \
                          delay(1000); \
                          this->sendVector(&cmd_data); \
                        } else
    CMDIF(ventilation_level_0)
    CMDIF(ventilation_level_1)
    CMDIF(ventilation_level_2)
    CMDIF(ventilation_level_3)
    CMDIF(boost_10_min)
    CMDIF(boost_20_min)
    CMDIF(boost_30_min)
    CMDIF(boost_60_min)
    CMDIF(boost_end)
    CMDIF(auto)
    CMDIF(manual)
    CMDIF(bypass_activate_1h)
    CMDIF(bypass_deactivate_1h)
    CMDIF(bypass_auto)
    CMDIF(ventilation_supply_only)
    CMDIF(ventilation_supply_only_reset)
    CMDIF(ventilation_extract_only)
    CMDIF(ventilation_extract_only_reset)
    CMDIF(temp_profile_normal)
    CMDIF(temp_profile_cool)
    CMDIF(temp_profile_warm)
    ;
  }
  void sendHex(std::string hexSequenceToSend) {
    std::vector<uint8_t> bytes;
    bytes.reserve(hexSequenceToSend.length() / 2);
    for (unsigned int i = 0; i < hexSequenceToSend.length(); i += 2) {
        std::string byteString = hexSequenceToSend.substr(i, 2);
        uint8_t byte = (uint8_t) strtol(byteString.c_str(), NULL, 16);
        bytes.push_back(byte);
    }
    this->sendRaw(bytes.size(), bytes.data());
  }
  void sendVector(std::vector<uint8_t> *data) {
    this->sendRaw(data->size(), data->data());
  }
  void sendRaw(uint8_t length, uint8_t *buf){
     sequence++;
     sequence = sequence & 0x3;
     CAN_FRAME message;
     message.extended = true;
     message.rtr = 0;

     if (length > 8) {
         CanAddress addr = CanAddress(0x3a, 0x1, 0, 1, 0, 1, this->sequence);
         uint8_t dataGrams = length / 7;
         if (dataGrams * 7 == length)  {
             dataGrams--;
         }
         for (uint8_t i = 0; i < dataGrams; i++) {
             memset(message.data.byte, 0, 8);
             message.data.uint8[0] = i;
             message.length = amin((i*7)+7, length) - i*7 + 1;

             message.id = addr.canID();
             memcpy(& message.data.uint8[1], &buf[i * 7], message.length - 1);
             CAN0.sendFrame(message);
         }
         // Send last packet
         memset(message.data.uint8, 0, 8);
         message.data.uint8[0] = dataGrams | 0x80;
         message.length = length - dataGrams * 7 + 1;
         memcpy(& message.data.uint8[1], &buf[dataGrams * 7], length - dataGrams * 7);
         CAN0.sendFrame(message);

     } else {
         CanAddress addr = CanAddress(0x3a, 0x1, 0, 0, 0, 1, this->sequence);
         message.id = addr.canID();
         message.length = length;
         memcpy(message.data.uint8, buf, length);
         CAN0.sendFrame(message);

     }
  }

  void setup() override{
     CAN0.setCANPins( (gpio_num_t) this->rx_, (gpio_num_t) this->tx_);
     CAN0.begin(50000);
     CAN0.watchFor();
     register_service(&Comfoair::send_command, "send_command", {"command"});
     register_service(&Comfoair::sendHex, "send_hex", {"hexSequence"});
     register_service(&Comfoair::req_update_service, "req_update_service", {"PDOID"});
     register_service(&Comfoair::update_next, "update_all", {});
     this->update_next();
  }

  void update_next() {
    if (update_iterator_ >= (int)PDOs.size()) {
        update_iterator_ = 0;
        if (!boot_recheck_done_) {
            // First pass done — schedule a second pass after 30s to fix
            // boot-time CAN artifacts (e.g. fan_speed PDO returning 0 briefly).
            boot_recheck_done_ = true;
            set_timeout("update_recheck", 30000, [this](){this->update_next();});
        }
        return;
    }

    int currentPDO = PDOs[update_iterator_];
    this->request_data(currentPDO);
    update_iterator_++;
    ESP_LOGD(TAG, "update_next %d - iterator %d", currentPDO, update_iterator_);
    set_timeout("update_next", 1000, [this](){this->update_next();});
  }
  void req_update_service(float pdo){
    this->request_data((int)pdo);
  }
  void request_data(int PDOID) {
//    CanAddress addr = CanAddress(0x3, 0x1, 0, 0, 0, 1, this->sequence);
    CAN_FRAME message;
    message.extended = true;
    message.rtr = 1;
    message.id = (PDOID << 14) + 0x40 + 0x3a;

    message.length = 0;
    CAN0.sendFrame(message);
  }

  void loop(){
    // ESP_LOGD(TAG, "loop");
    if (CAN0.read(canMessage)) {
        uint16_t PDOID = (canMessage.id & 0x01fff000) >> 14;
        uint8_t *vals = &canMessage.data.uint8[0];
        
        auto sensor_it = sensors.find(PDOID);
        if (sensor_it != sensors.end()) {
            const auto& el = sensor_it->second;
            float sensorVal;
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

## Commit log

2021-01-23 added f3d
    [box-vmc v20.f3d]
2021-01-23 3d stuff
    [box-vmc v20.f3d, box-vmc-sotto-finale.stl, cappella-box-vmc.stl]
2021-07-10 changes to messages.cpp - add new message types (bypass_activation_mode, pre_heater_temp_before, pre_heater_temp_after) - reorder temp sensors - change bypass_state to percentage - adjust comment on 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
2022-05-13 Update platformio.ini
    1)Updated espressif32 platform version.
    As from platform package version 4.0.0 the ESP32 crashes with this software and throws out some weird FreeRTOS related errors.
    This is due to the updated framework-arduinoespressif32 as of version 4.0.0
    I tested different platform package versions and 3.5.0 was the last stable one.
    2)Added extra info on line 16 and 18
    3)Added working proposals from issue #13
    Line22-24
    Line 35-37
2022-09-12 Update message.cpp
    fix for new values conflicting with temperatures.
2023-04-28 changed pic and added prod files for pcb
    [BOM_PCB_comfoair_2_2023-04-28.csv]
2023-04-28 start readme
    [box-vmc v20.f3d, box-vmc-sotto-finale.stl, cappella-box-vmc.stl]
2023-05-22 fix #47 rollback due to changes in esp32_can lib.
2024-07-02 added selfupdate and services to avoid unavailable
    fix #55
    [comfoair.h]
2024-07-03 :fix pdo is not u8
    [comfoair.h]
2024-07-03 :fix add target temperature to the climate entity
    [comfoair.h]
2024-07-03 :feat global filters
2024-07-04 changed some sensors to binary and added manual_mode
2024-07-08 :fix build and sample
    [comfoair.h]
2025-11-10 Fix climate entity for ESPHome 2024+ compatibility
    - Migrate climate registration to new ESPHome API (climate.register_climate)
    - Remove deprecated App.register_climate() call
    - Add climate module import
    - Keep esp32_can library at latest commit (6d835ae from 28 Mar 2025)
2025-11-10 Fix critical memory leaks and performance optimizations
    - Fix memory leak in send_command(): Remove 'new' without 'delete' for vectors
    - Optimize string parameters: Use const std::string& instead of pass-by-value
    - Eliminate duplicate map lookups: Store iterator results and reuse
    - Avoid unnecessary copies: Use const auto& for sensor objects
    - Improve float comparisons: Cast to int for discrete fan levels
    - Add vector reserve() for better performance in sendHex()
    - Remove dead commented code in __init__.py
    [comfoair.h]
2025-11-10 Fix async/await issue and ESPHome API compatibility
    - Add missing 'await' for climate.register_climate() coroutine
    - Revert service method signatures to pass-by-value for ESPHome API compatibility
    (send_command and sendHex need std::string, not const std::string&)
    - Keep internal optimizations (const auto&, single map lookups, etc.)
    Fixes linker errors with undefined references to get_execute_arg_value
    [comfoair.h]
2025-11-10 Fix remaining const std::string& references in registration methods
    [comfoair.h]
2025-11-10 Register string services via Python API instead of C++ register_service to avoid template issues
    [comfoair.h]
2025-11-10 docs: Add comprehensive YAML configuration examples
    - Add esphome_sample_with_climate.yaml: Simple practical example with climate entity
    - Add esphome_complete_reference.yaml: Complete reference with all 46 sensors, 3 text sensors, 6 binary sensors
    - Document all available commands (27 total) and 4 custom services
    - Include boost buttons, mode selects, and special ventilation modes
    - Add detailed comments for PDO IDs, units, and sensor descriptions
2026-03-25 fix: ESPHome 2026.3+ compatibility (#93)
    - Guard sensor filter codegen behind USE_SENSOR_FILTER define
    - Use set_filters() instead of removed add_filters()
    - Replace deprecated ClimateTraits setters with add_feature_flags()
    - Document custom_services: true requirement in sample YAMLs
    [comfoair.h, esphome_complete_reference.yaml]
2026-03-29 fix: ignore boot-time RTR zero for fan_speed PDO
    PDO 65 (fan_speed) always returns 0 when polled via RTR right after
    the CAN bus is established. The correct value only arrives as a
    spontaneous TPDO when the fan speed actually changes.
    This caused fan_speed to incorrectly show 0 after every reboot,
    which also set the climate entity fan_mode to OFF.
    Fix: suppress fan_speed=0 publishes until at least one non-zero
    value has been received (fan_speed_initialized_ flag). After that,
    0 is valid (unit in away/off mode) and published normally.
    Also replaced static local variable in update_next() with proper
    member variables (update_iterator_, boot_recheck_done_) and added
    a second PDO poll pass 30s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
    [comfoair.h]
